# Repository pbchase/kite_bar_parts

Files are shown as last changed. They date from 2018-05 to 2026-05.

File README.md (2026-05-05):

# 3D models of components for kite control bars

This repository is a collection of 3D models for components that could be used in the construction of kite control bars. The models were created with OpenSCAD, a programming language and development environment for 3D modelling. Some of these modules are complete components that have been used in actual gear. Some are speculative designs. Other are primitives used as part of a complete component.

## How to view and manipulate these models

These OpenSCAD models can be opened, viewed, and revised using free software found at [www.openscad.org](http://www.openscad.org/). The software is available for Mac OS X, Windows, and Linux.

For the most basic use, download and install OpenSCAD. Open a model and preview it. Use the viewer controls to examine the model from all sides.

To make changes you need only basic programming skills. The editor window of OpenSCAD will show the code that generates the model. Revise the values of variables defined in the file and preview the revised model to understand how each variable affects the model. Note that all dimensions are in millimeters.

## How to print these models

To print a model, use OpenSCAD to generate a vector file in STL format. Most 3D printers can use an STL file as input.

Default 3D printer settings often use a minimal number of shells and a sparse infill that is too weak to handle the loads required  for these components. To address this, use at least 3 shells and a high infill. 80% infill is not unreasonable.

Most of these designs do not need supports. In some cases overhangs have been specifically tailored to meet the Makerbot's maximum overhang recommendation of no more than 68 degrees off vertical.

## Current models

[separation\_block_v3](separation_block_v3.scad) - This component transfers load from the main flying lines by providing a pair of parallel bore holes. Each flying line passes through a bore hole. The flying line is trapped on the lower side of the block via a larks head of relatively fat line. The pair of bore holes surround a larger, toroidal central bore hole. The curved central bore provides a low friction path for the trim line. An 80-facet-count STL files has been generated with a [8mm](printable/separation_block_v3_8mm_trimline_bore_2026-05-05.stl) trim line bore. Weaker versions of this model have been tested with a 4mm Amsteel trimline with a brummel-spliced loop on the lower end. While the trim line is only 4mm in this component, the 8mm diameter of the spliced loop must pass through it for assembly.

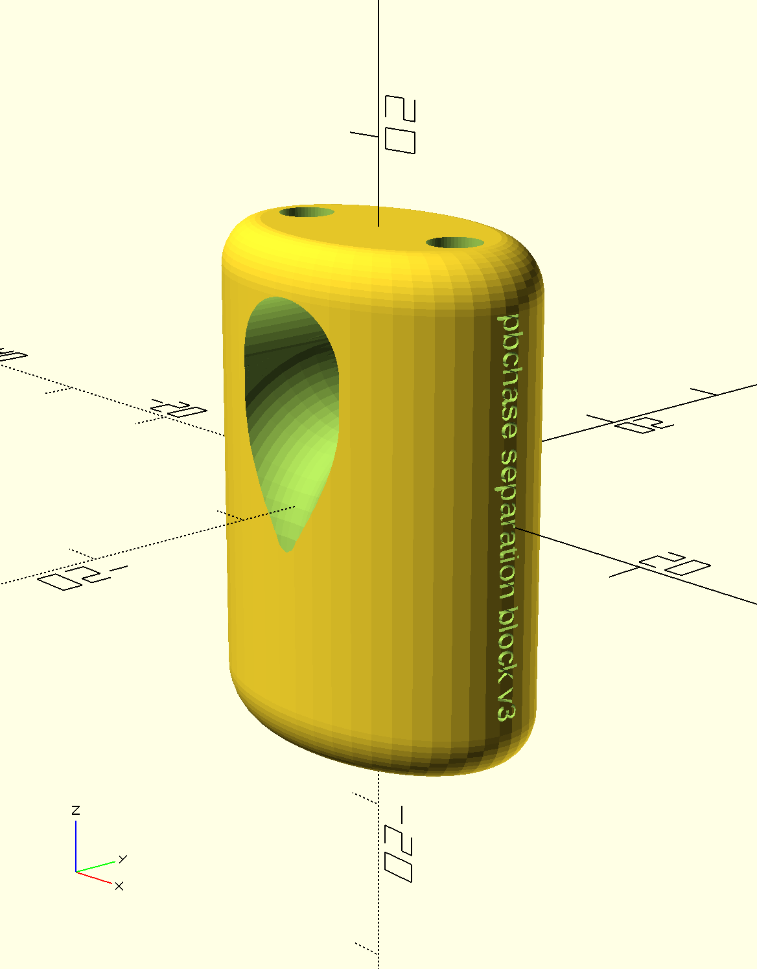
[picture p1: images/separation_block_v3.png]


[cleat_bead](cleat_bead.scad) - This component is meant to mate on to the pilot-end of [Clamcleat® CL826-11](https://www.clamcleat.com/aero-cleat-with-cl211-mk2.html). It fits tightly onto the end of the cleat with a positive rotational lock. The spherical shape conforms to the circular hole in the kite-side of the bar and allows for easy bar spinning.  The rotational lock allows for a flag-line guide path to be routed away from the jaws of the cleat to reduce the risk of cleating the flag line. STL files have been generated for [5mm](printable/cleat_bead_2026-04-28.stl) trim lines.

The small hole in the side accommodates a 18-8 Stainless Steel Cone-Point Set Screw mith 10-32 threads, 1/2 inch long. I used [item 92785A337](https://www.mcmaster.com/92785A337/) at McMaster Carr. It uses a 3/32" hex drive. Use the set screw to tap the hole by first heating it to a low heat with a torch, then screwing it in. The set screw should be screwed into the rope in the serpentine to lock the cleat bead to the cleat. This keeps the bead in place when the pilot pulls on it. 

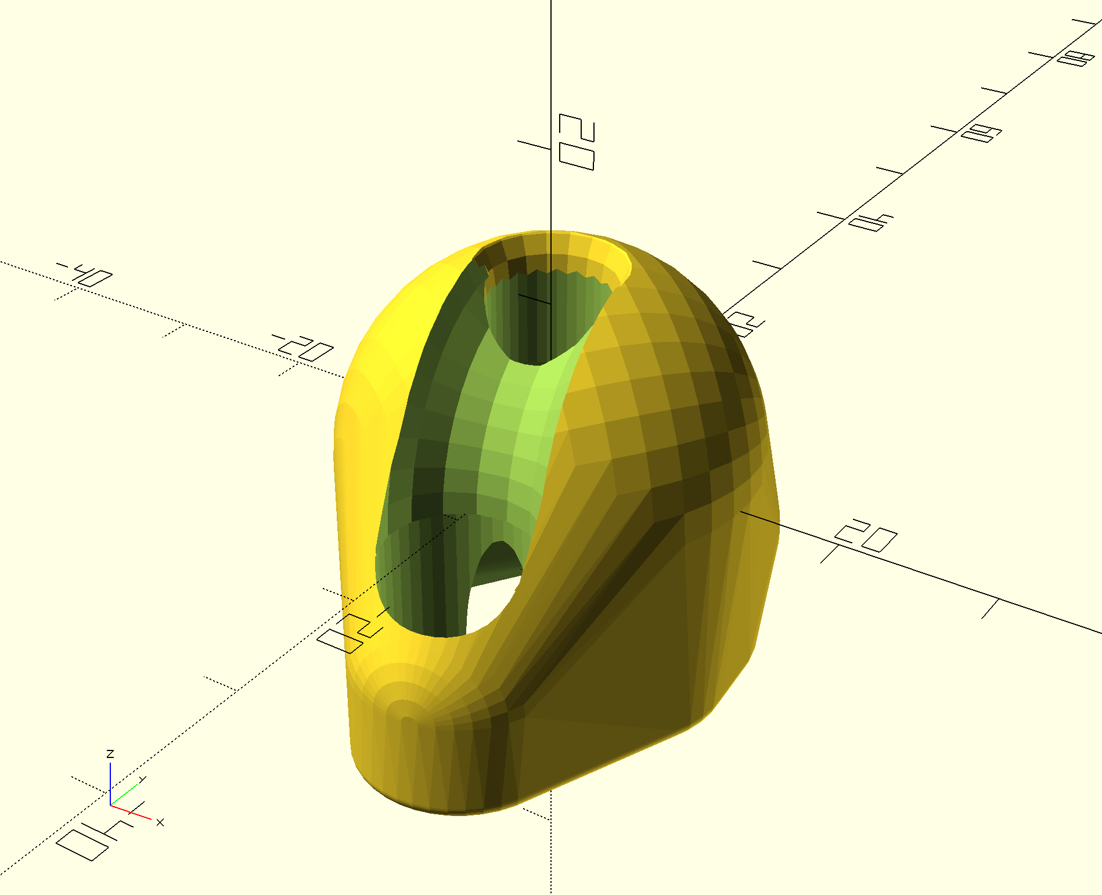
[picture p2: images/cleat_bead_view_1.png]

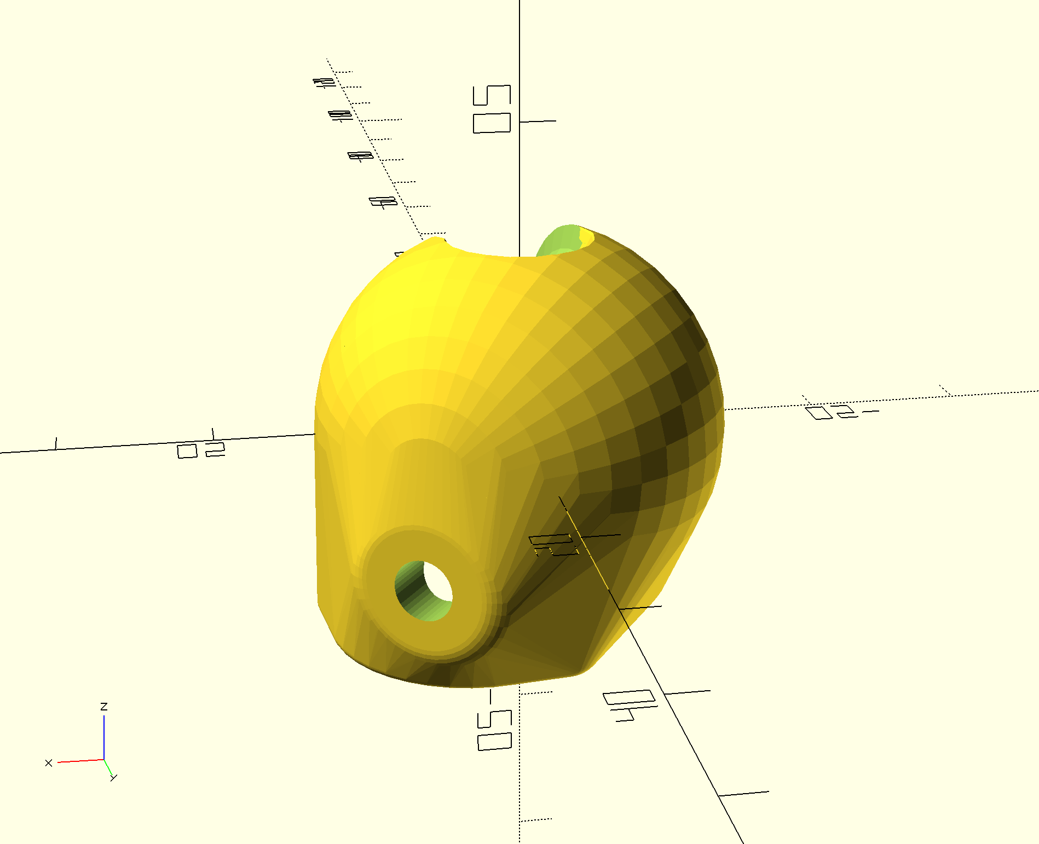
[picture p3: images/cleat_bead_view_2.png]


## Deprecated models

Several [deprecated designs](deprecated.md) and [primitives](primitives.md) used in many of these designs are also available in this repo.

## Contributing

If you would like to contribute revisions to these models or add new models feel free to fork this repo, make changes and submit a pull request. You are also welcome to open an issue and attach a file or send me files at philipbchase@gmail.com. All contributions should include a Creative Commons Public Domain license.

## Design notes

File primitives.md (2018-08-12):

### Primitives

[elliptical\_cone](elliptical_cone.scad) - a primitive the generates a vertically orients cone with a profile of 1/4 of an ellipse.

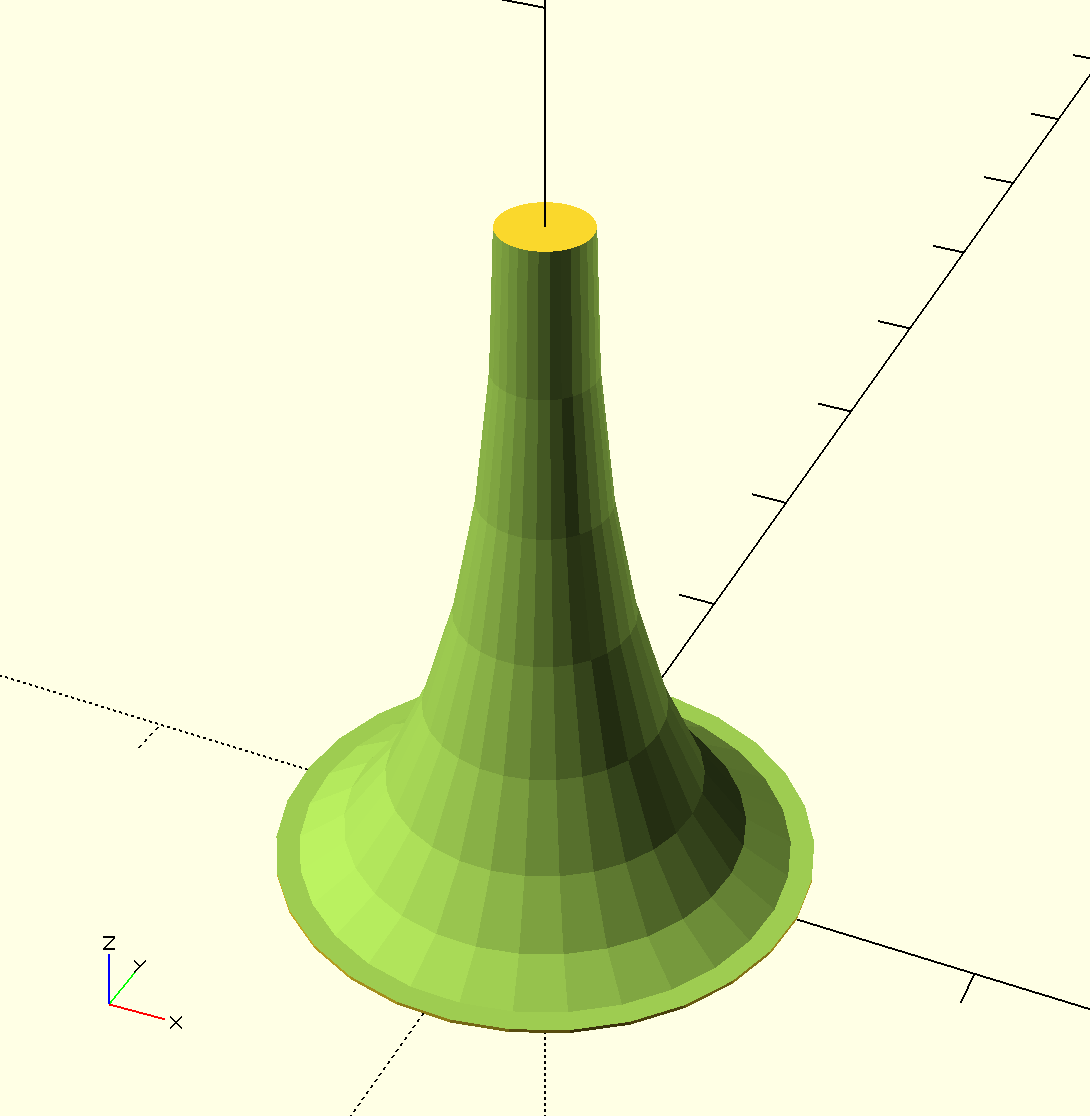
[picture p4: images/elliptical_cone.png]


[elliptical\_torus](elliptical_torus.scad) - a primitive the generates a torus with a eliptical cross section. It includes a primitive for an ellipse as well.

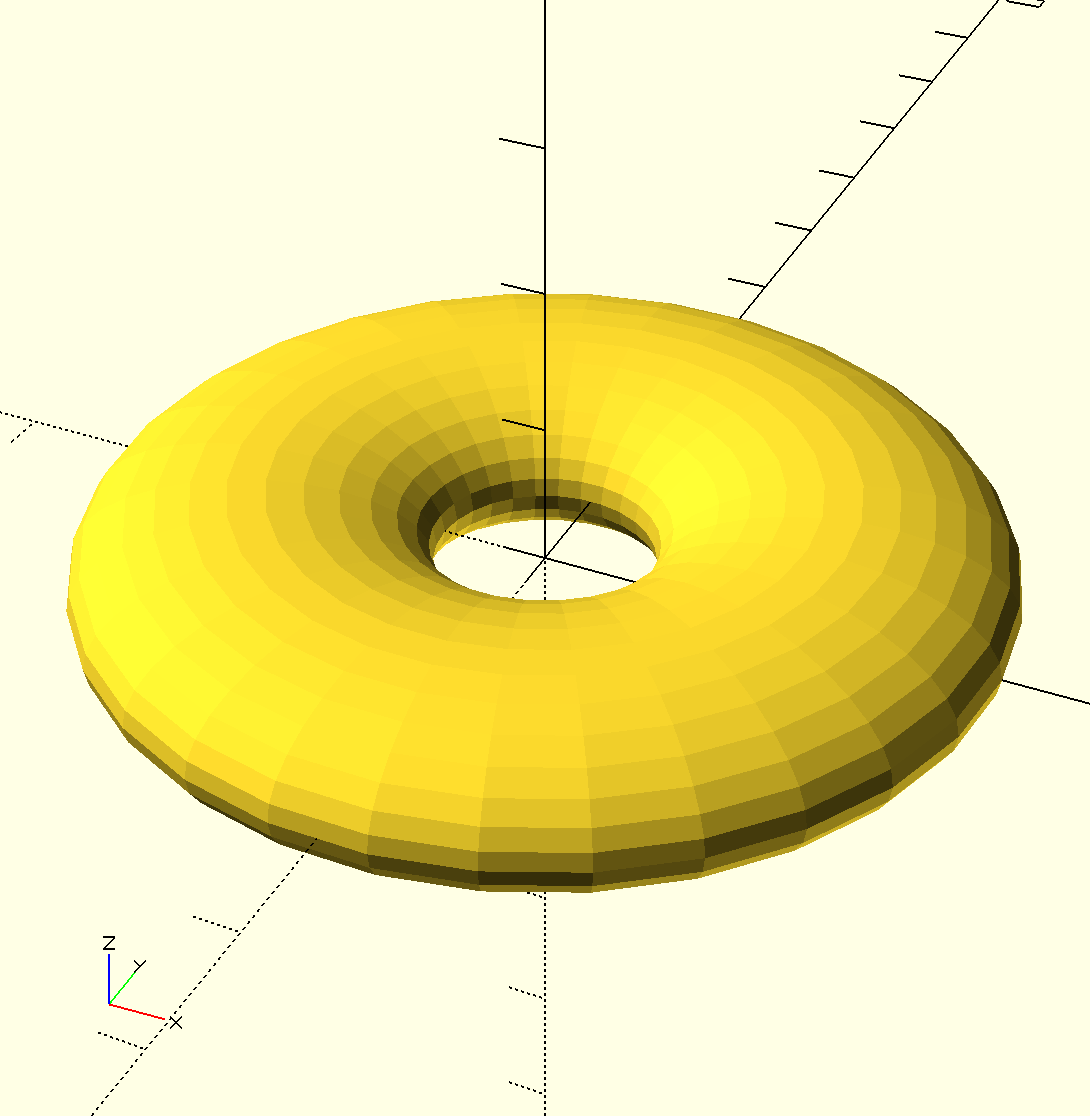
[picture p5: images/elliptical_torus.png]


[fillet\_around\_cylinder\_base](fillet_around_cylinder_base.scad) - a primitive that generates a cylinder surrounded by a 1/4 circle fillet.

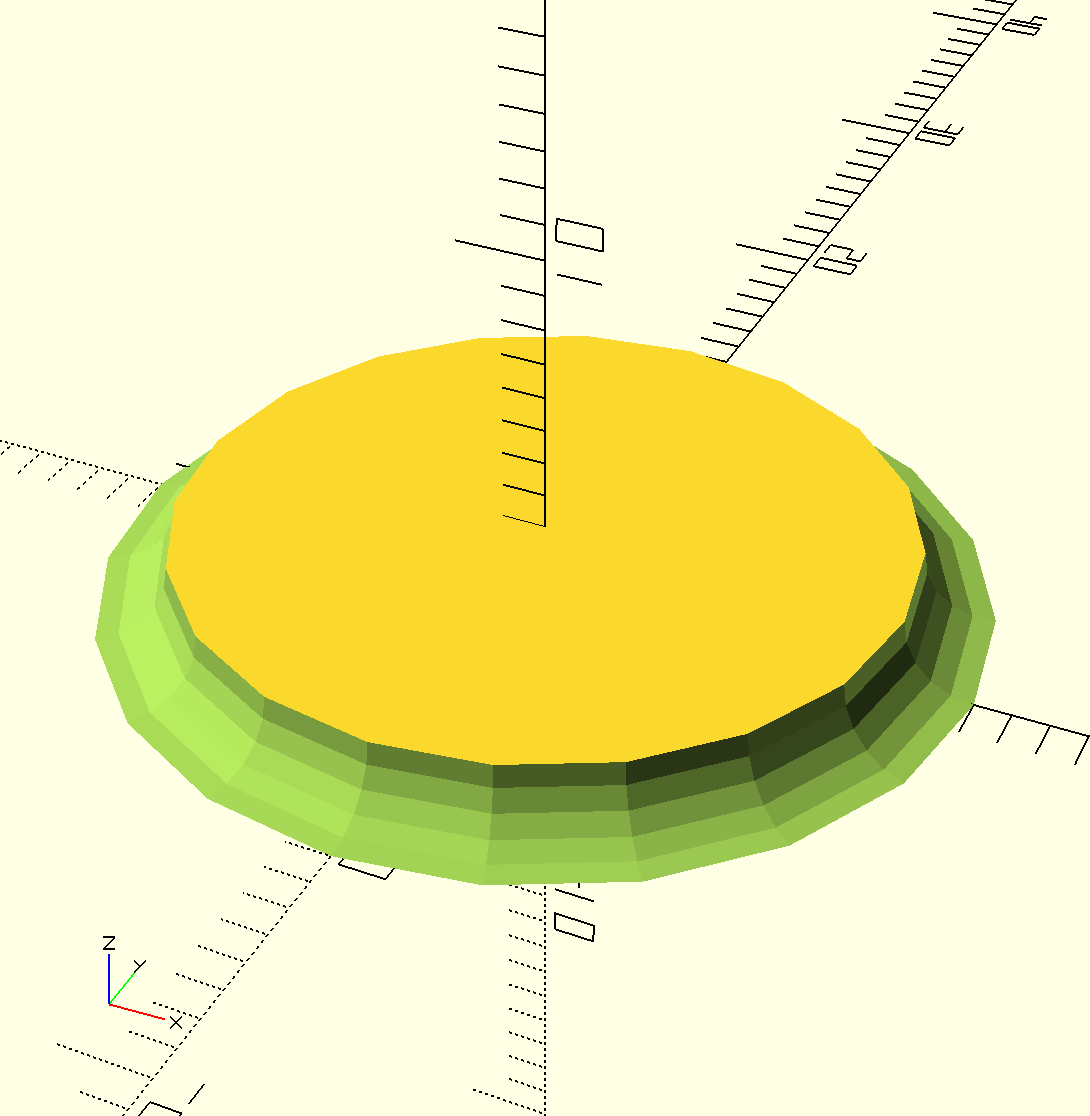
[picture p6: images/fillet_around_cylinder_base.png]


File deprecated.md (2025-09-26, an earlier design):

# Deprecated Designs

These designs have all been superceded by more functional shapes or have been otherwise retired.

## chickenloop_release

I've resisted the use of chickenloops for quite sometime, but every snap shackle I have tried presents issues in reliable use for newbies, or inadvertent release for experienced fliers. It's hard to beat the simplicity of a chickenloop with a push-away release. [chickenloop_release](chickenloop_release.scad), is the model for that release. The release doubles as a below-the-bar handle for the kite. As an Arc flier this is valuable feature for handling the kite while it's parked at zenith. The release is designed to accommodate a doubled trimline of 4mm Amsteel Blue through the center bore. A 0.102" stainless steel pin crosses and divides the center bore to provide a retainer for the trimline. The prototypes for this model use a 40mm stainless steel cotter pin to retain the free end of the chickenloop. The side bores retain a segment of 1/8" bungie that pushes the chickenloop and cotter pin together. A 90-facet-count [STL file](printable/chickenloop_release_d1928a2.stl) is available.

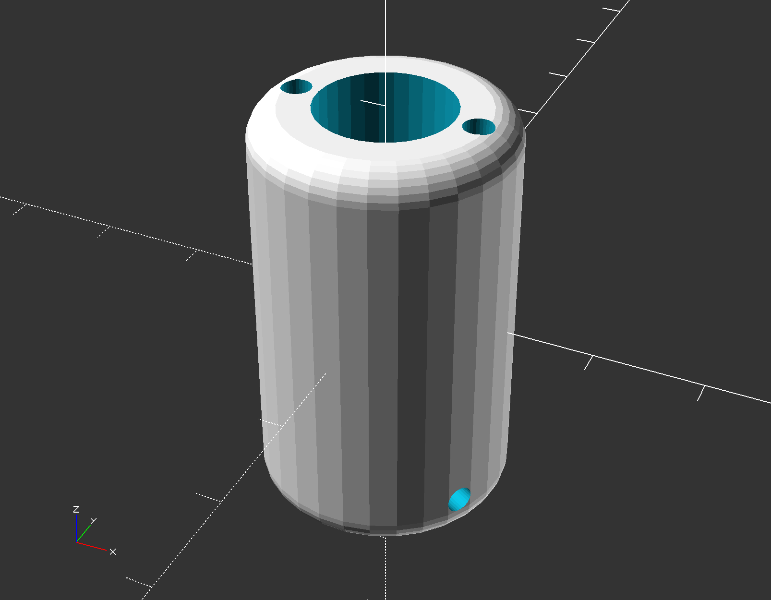
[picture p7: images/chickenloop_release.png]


[stopper\_ball](stopper_ball.scad) - The ball used in a moveable stopper on a kite bar trim line. STL files have been generated for
[4mm\_amsteel\_blue\_trimline](printable/stopper_ball_4mm_amsteel.stl) and
[5mm\_amsteel\_blue\_trimline](printable/stopper_ball_modern_5mm_amsteel.stl). The previous iteration of this ball was field tested and worked very well. This iteration removes a twist in the bungie path. To print it reliably, use a support structure that surrounds the base.

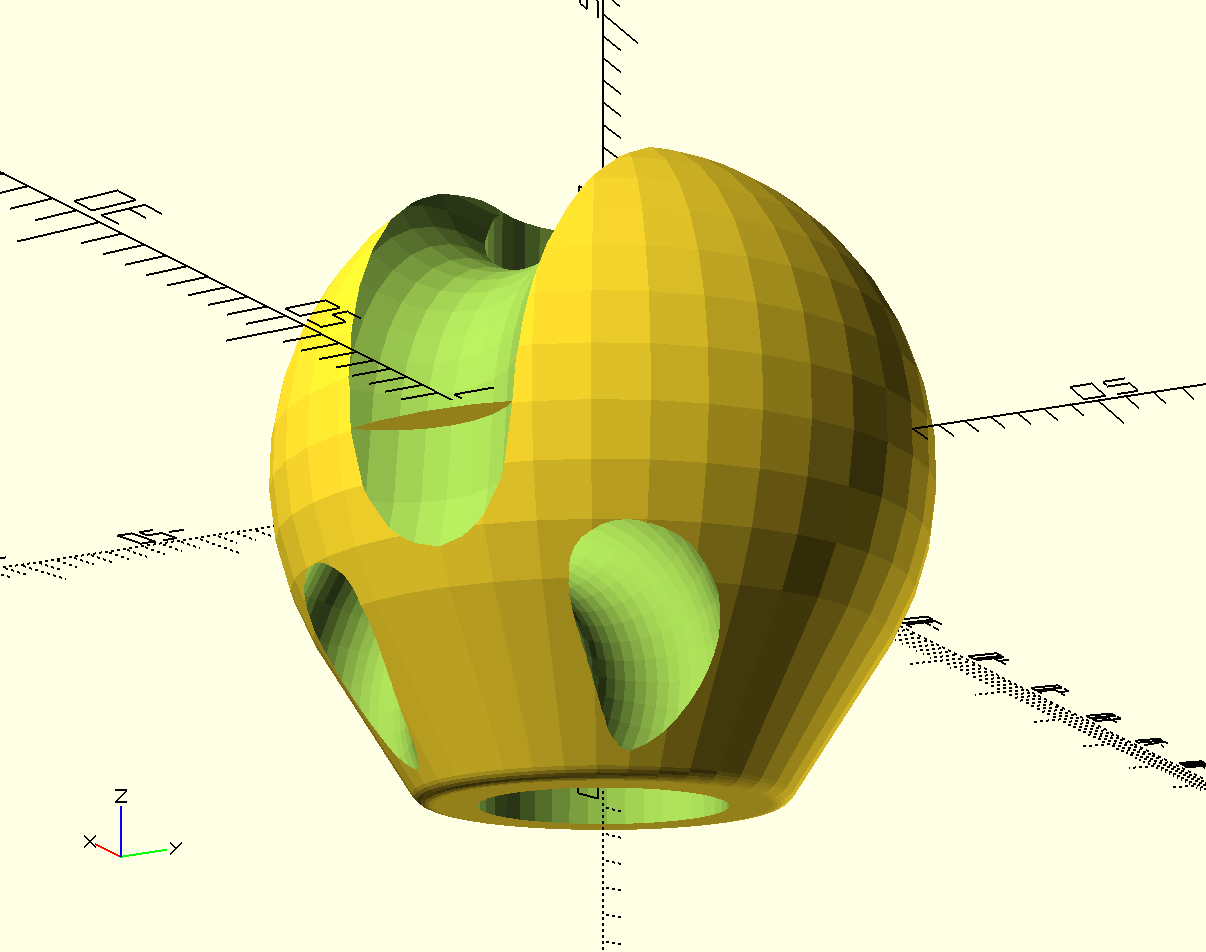
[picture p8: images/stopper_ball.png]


[stopper\_block\_v4](stopper_block_v4.scad) - This block is used in tandem with the stopper ball to form a moveable stopper. A slightly earlier version of this design has been field tested. This version should be easier to print than the previous version. STL files have been generated for
[4mm\_amsteel\_blue\_trimline](printable/stopper_block_v4_4mm_amsteel.stl) and
[5mm\_amsteel\_blue\_trimline](printable/stopper_block_v4_modern_5mm_amsteel.stl).

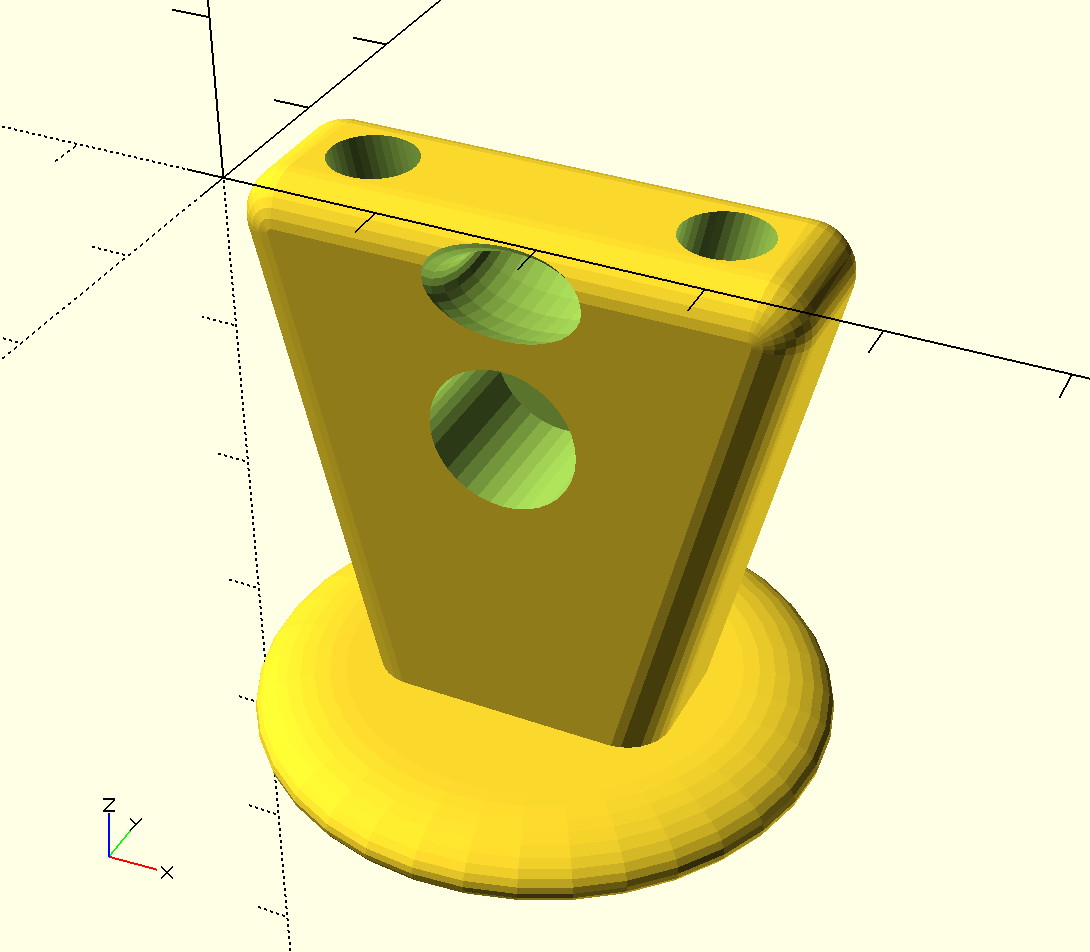
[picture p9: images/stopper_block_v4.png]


[separation\_block_v1](separation_block_v1.scad) - This component transfers load from the main flying lines by providing a pair of parallel bore holes. Each flying line passes through a bore hole. The flying line is trapped on the lower side of the block via a larks head of relatively fat line. The pair of bore holes surround a larger, central bore hole. The central bore hole allows a heavier line to be secured to the separation block. The upper end is secured via an overhand knot. The lower end of the central line entraps a low friction ring that acts as a pulley for the trim line. An [STL File](printable/separation_block_v1_9a972b6.stl) is available.

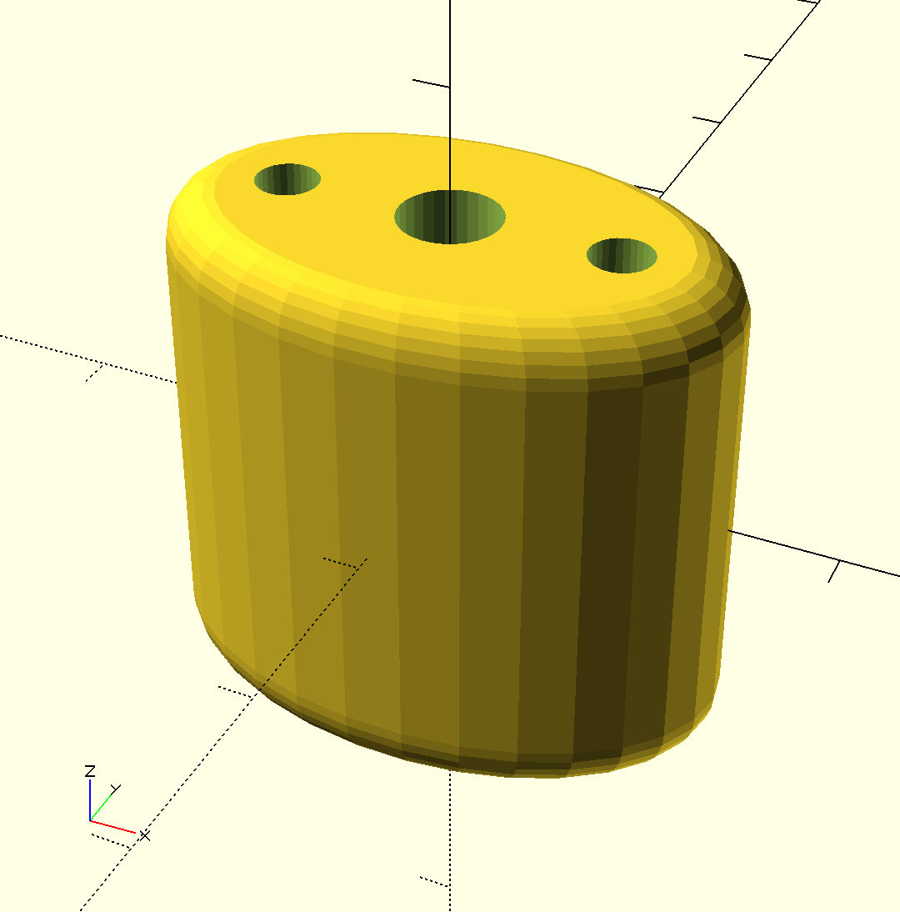
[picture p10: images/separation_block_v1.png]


**Three part wichard snaphook** -  This design is uses six components to form a fid and a handle to actuate a wichard snaphook. The components are
[wichard\_snaphook\_handle\_concave\_link](wichard_snaphook_handle_concave_link.scad),
[wichard\_snaphook\_cone\_fid](wichard_snaphook_cone_fid.scad) and
[wichard\_snaphook\_handle\_for\_cone\_fid](wichard_snaphook_handle_for_cone_fid.scad).  [STL files](printable/) are available for each.  A pair of each component is printed to out fit a single snaphook. This design accidentally released once in a 3 hour session. That's still too high.

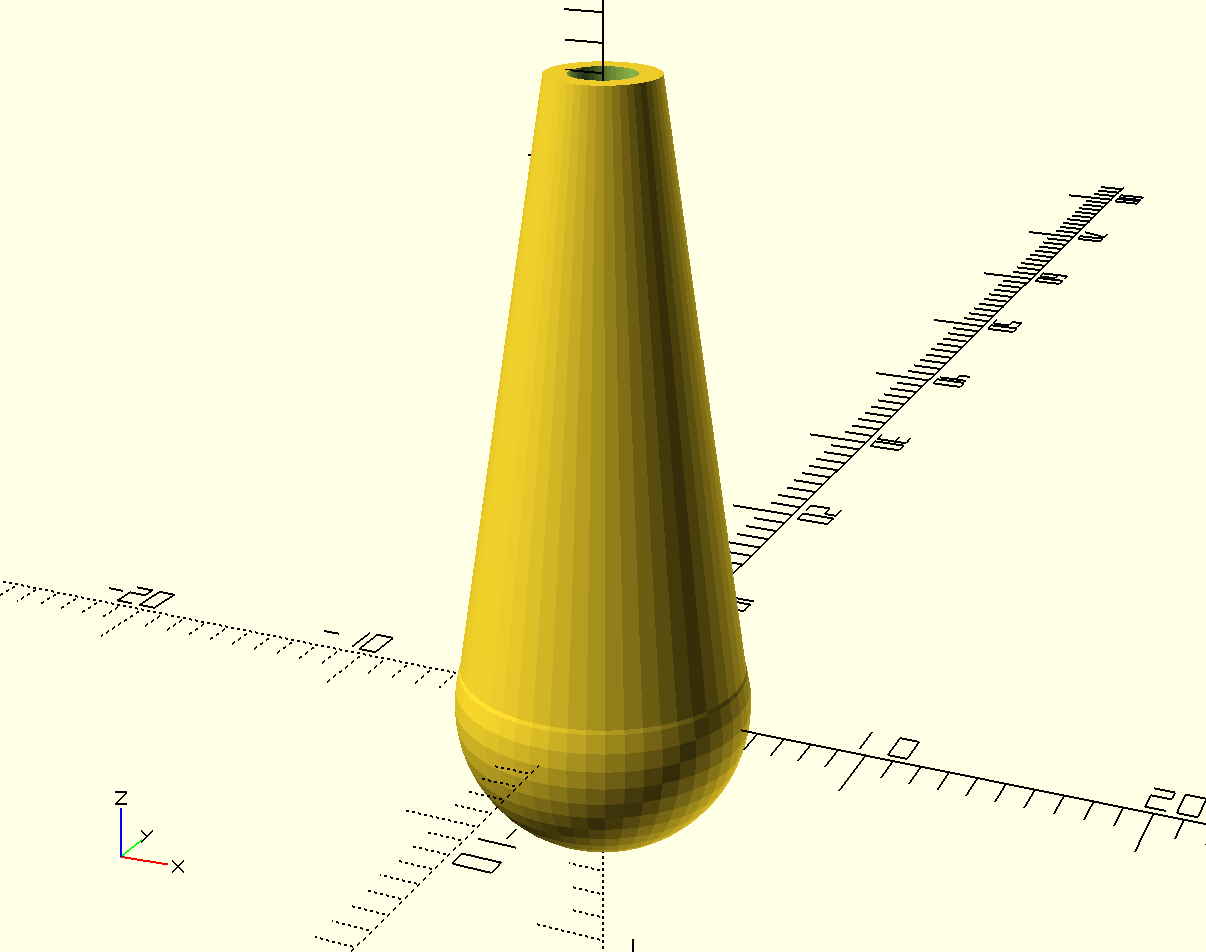
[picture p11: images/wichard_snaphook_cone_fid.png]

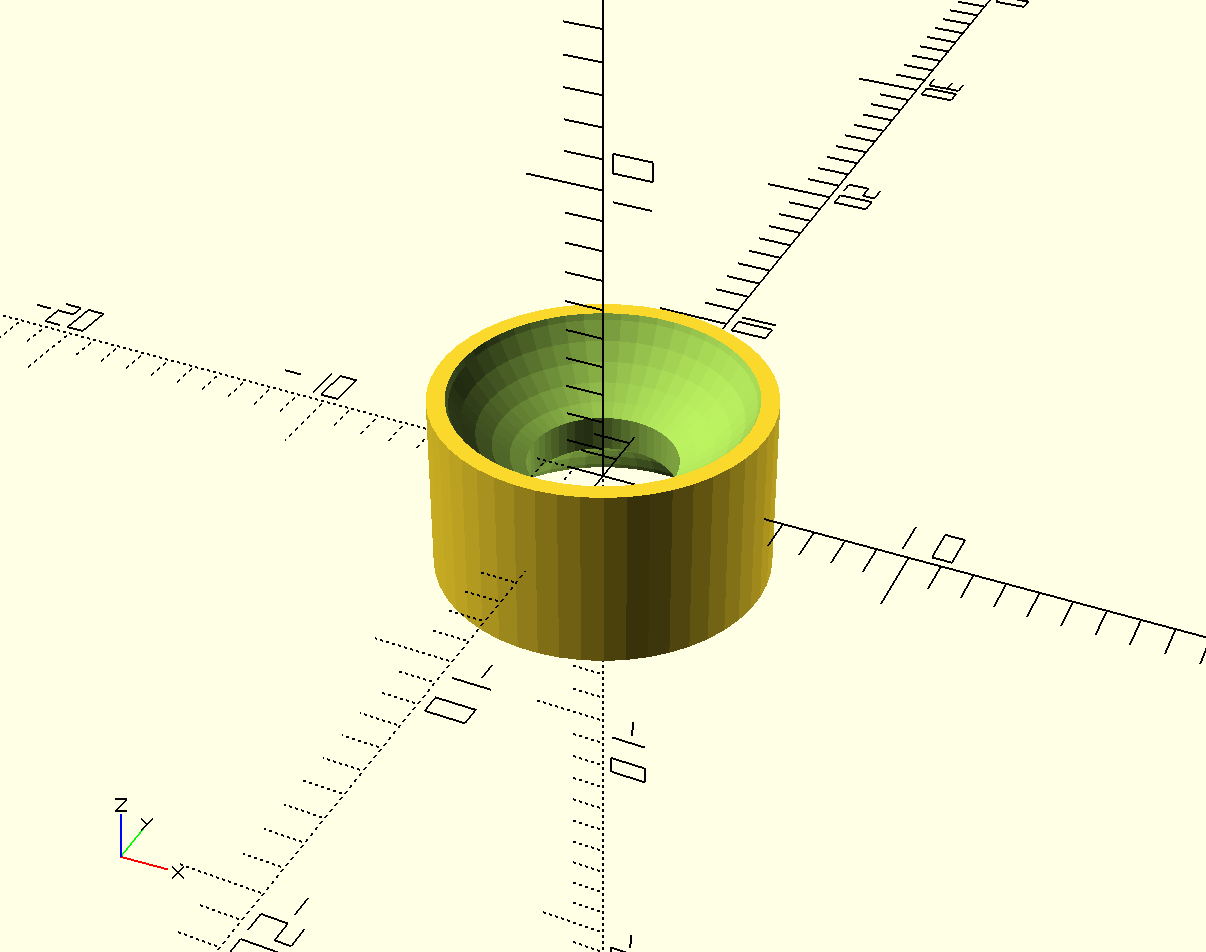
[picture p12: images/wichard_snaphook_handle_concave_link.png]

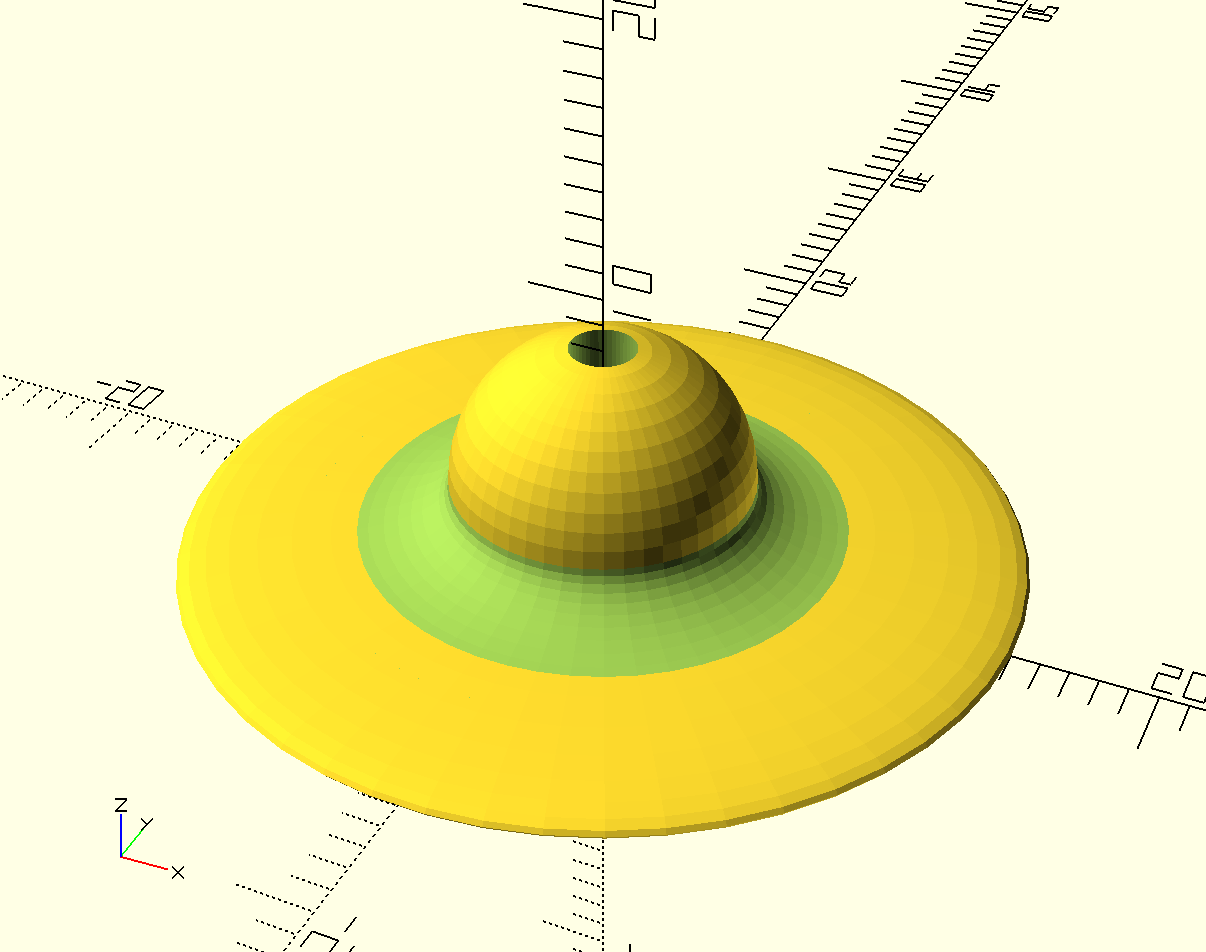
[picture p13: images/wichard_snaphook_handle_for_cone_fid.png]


[wichard\_snaphook\_handle\_golf\_tee\_style](wichard_snaphook_handle_golf_tee_style.scad) - a cone-and-flange handle to open the gate of a Wichard Snap shackle. An [STL file](printable/wichard_snaphook_handle_golf_tee_style_8677c59.stl) is available. While this model reliably opens the gate and does so with little force it has opened unexpectedly in field testing. This happened three times in about 5 hours of testing. The problem occurs when the harness and the handles are forced down onto the pilot's thigh. Apprently, the base of the handle stands on the thigh as the snap hook is forced down against the thigh. This pulls the cord in the gate, pulls the opposite handle into the gate and triggers the release. See  _Untested Models_ below for the next iteration of the design.

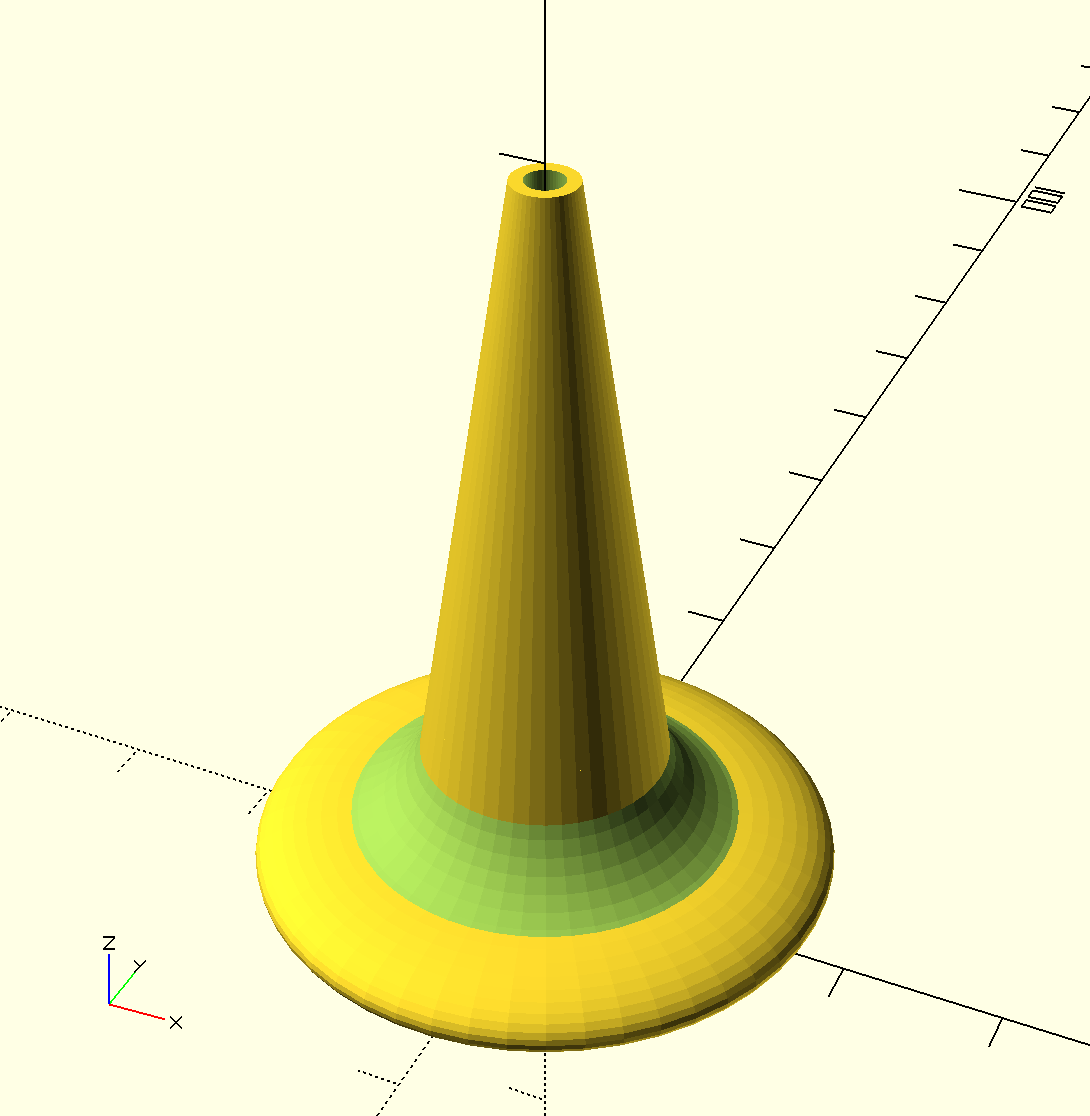
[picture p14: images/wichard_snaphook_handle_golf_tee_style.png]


[wichard\_snaphook\_handle](wichard_snaphook_handle.scad) - a cone-and-ball handle to open the gate of a Wichard Snap shackle. The wall thickness is thin at the base of the cone and the transition is harsh.

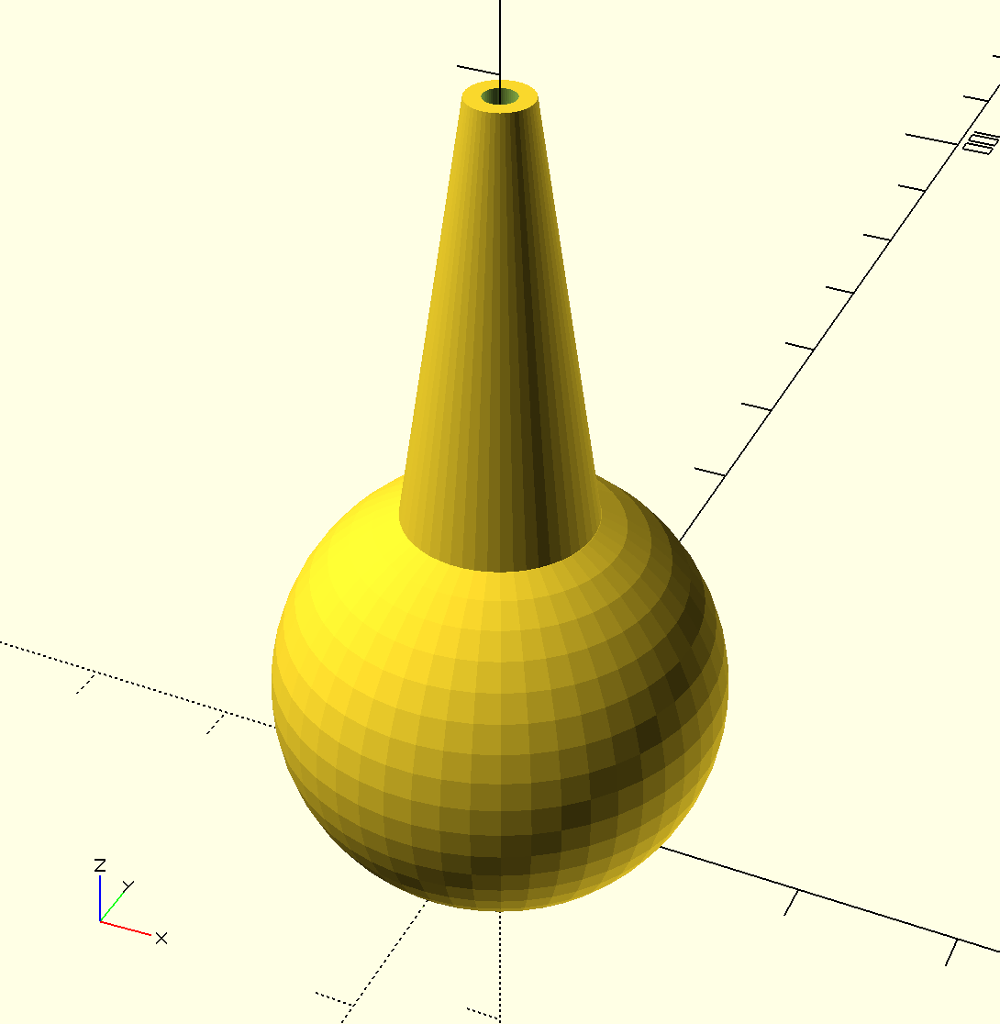
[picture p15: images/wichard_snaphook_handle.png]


[stopper\_block\_v3](stopper_block_v3.scad) - This block is used in tandem with the stopper ball to form a moveable stopper. This 3D model has never been tested in the field. It is 4mm narrow than stopper\_block\_v2 and uses octagonal horizontal bores to reduce overhang issues when printing. An [STL file](printable/stopper_block_v3_9c3c682.stl) is available.

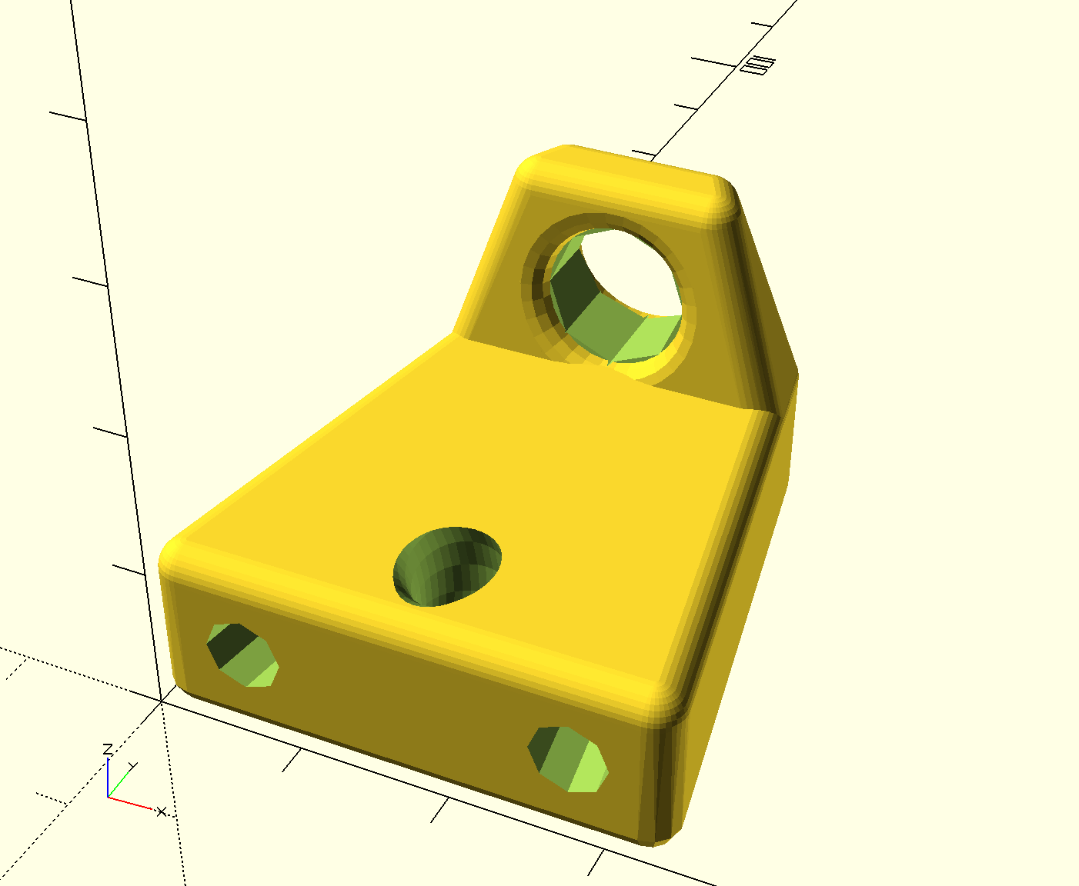
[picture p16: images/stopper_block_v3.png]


[stopper\_block\_v2](stopper_block_v2.scad) - This block is used in tandem with the stopper ball to form a moveable stopper. This 3D model has never been tested. That said, it is based on a hand-made design, cut from Delrin, that has been tested extensively. This model is closer to the hand-made design than the original [stopper\_block](stopper_block.scad) model.

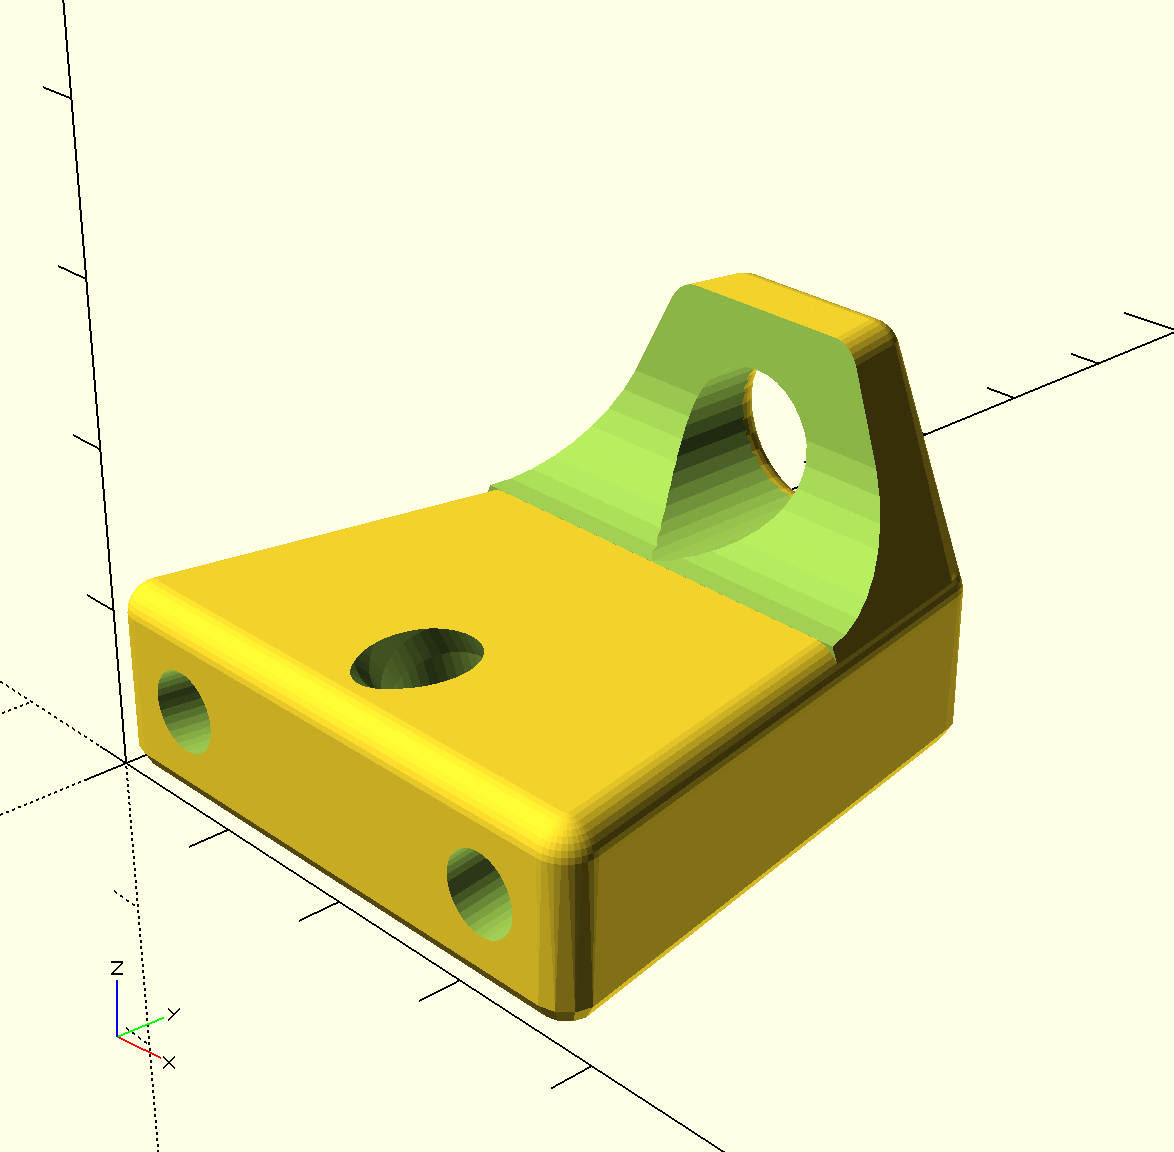
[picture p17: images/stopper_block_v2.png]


[stopper\_block](stopper_block.scad) - This block is used in tandem with the stopper ball to form a moveable stopper.  This 3D model has never been tested. That said, it is based on a hand-made design, cut from Delrin, that has been tested extensively.  The edges of this model are far harsher than what is possible when machining such a block from Delrin. The harsh edges might make it unsuitable for regular use.

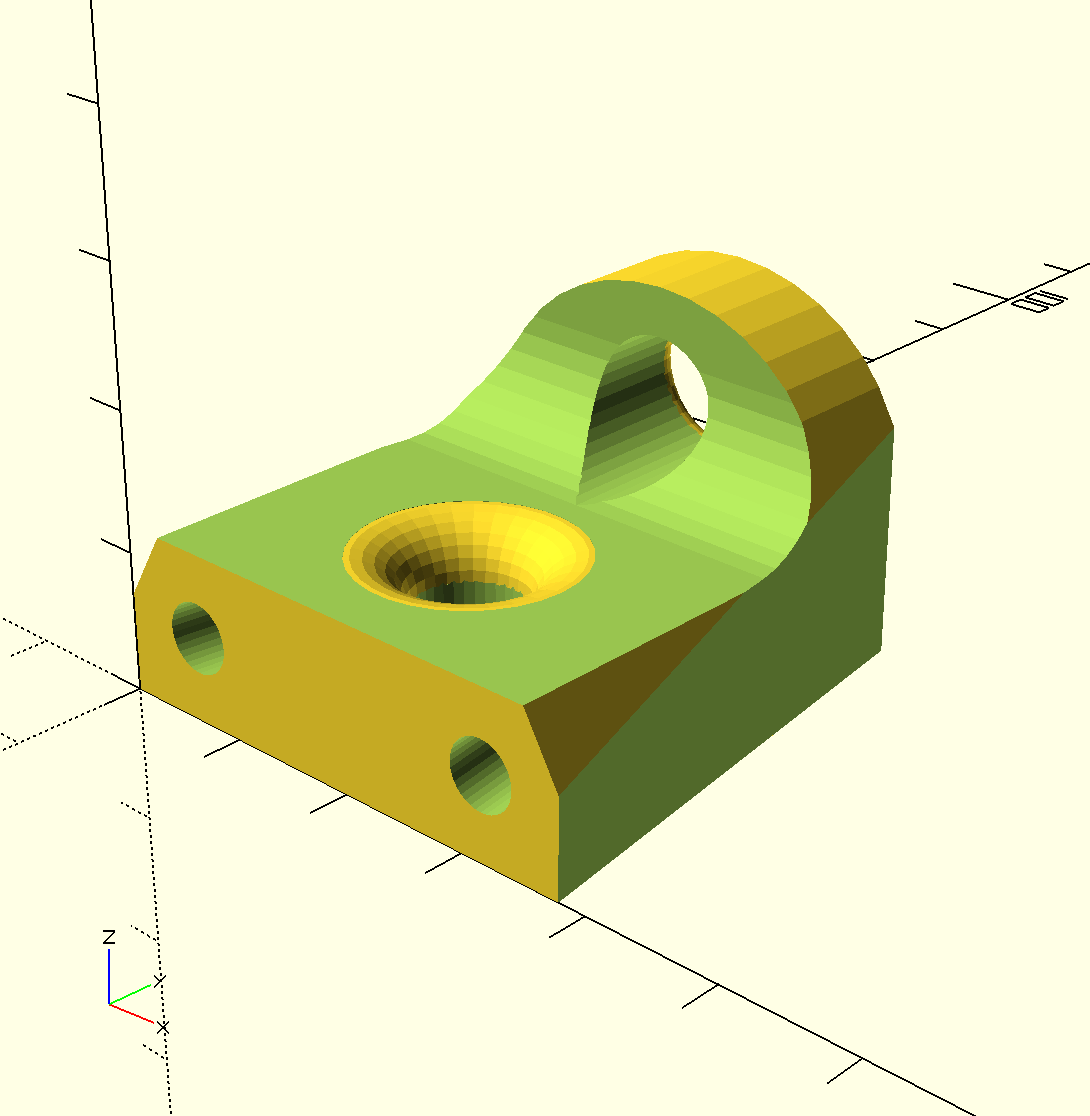
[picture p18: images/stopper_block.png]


[wichard\_snaphook\_release\_cone](wichard_snaphook_release_cone.scad) - a cone to open the gate of a Wichard Snap shackle.  This component has never been tested.

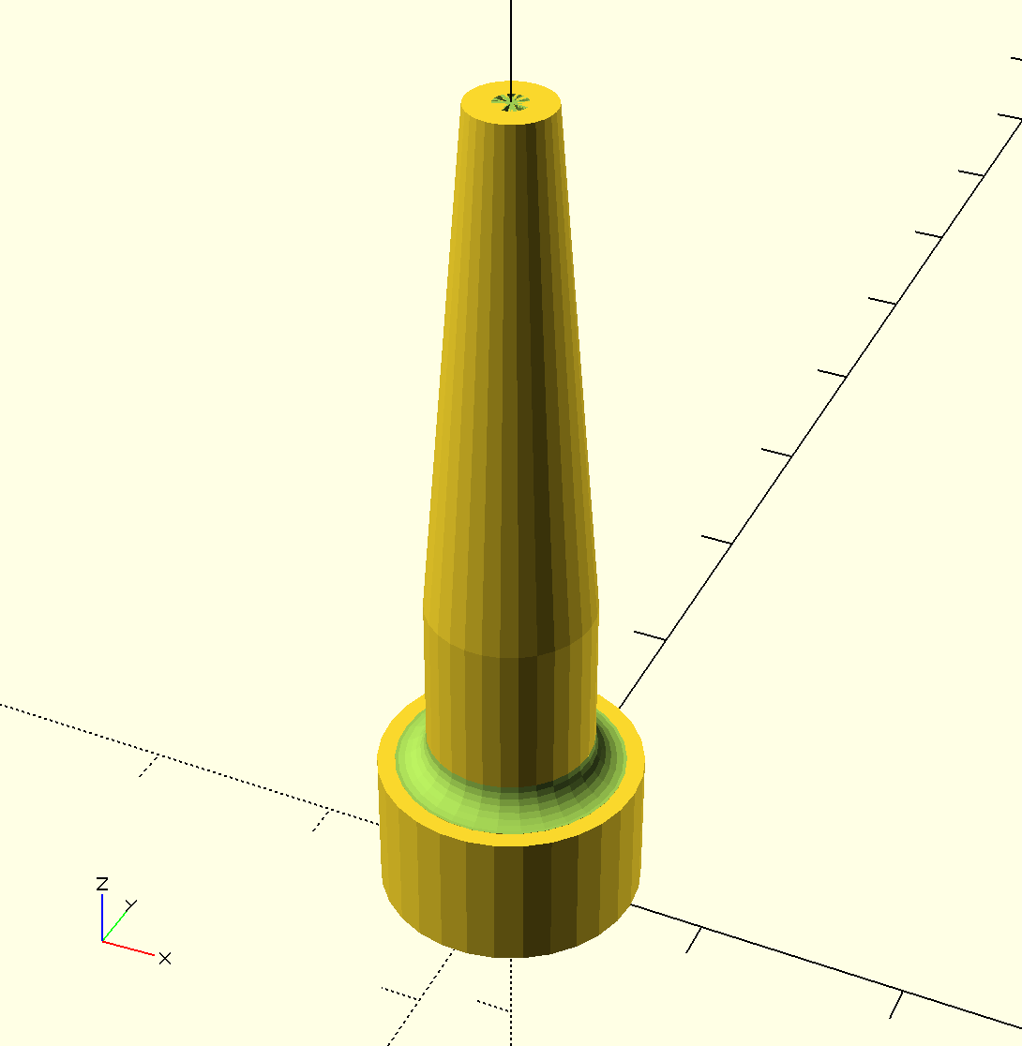
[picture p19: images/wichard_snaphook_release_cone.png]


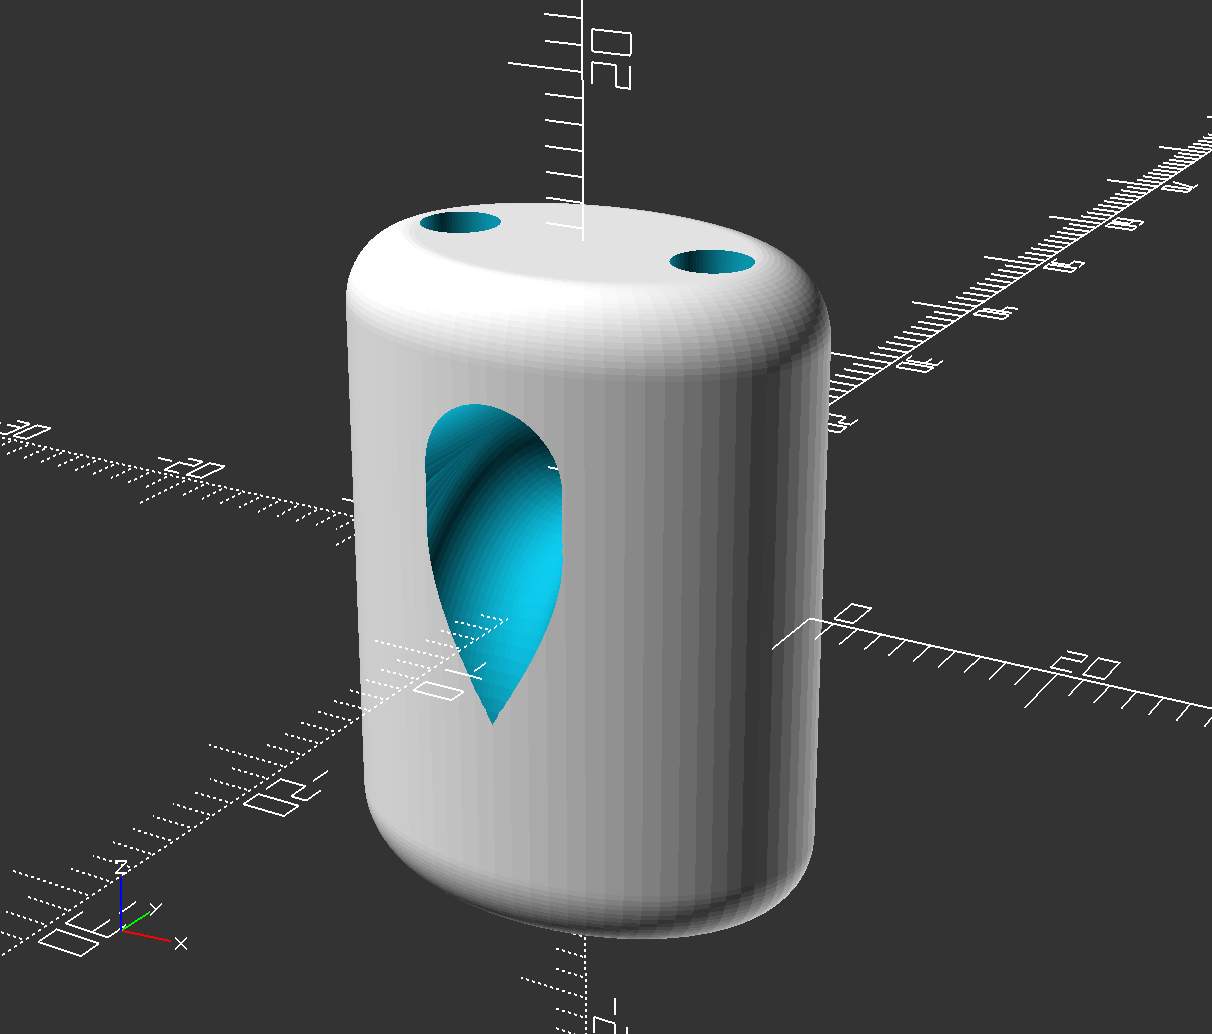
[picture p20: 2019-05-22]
images/separation_block_v2.png

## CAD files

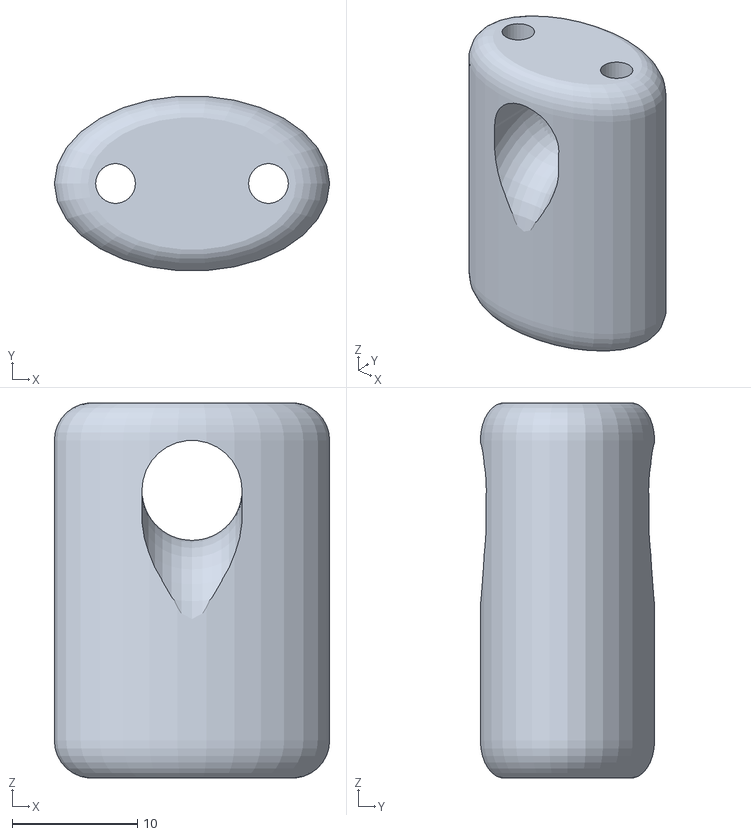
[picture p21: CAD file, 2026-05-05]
printable/separation_block_v3_8mm_trimline_bore_2026-05-05.stl
22.0 x 13.9 x 30.0

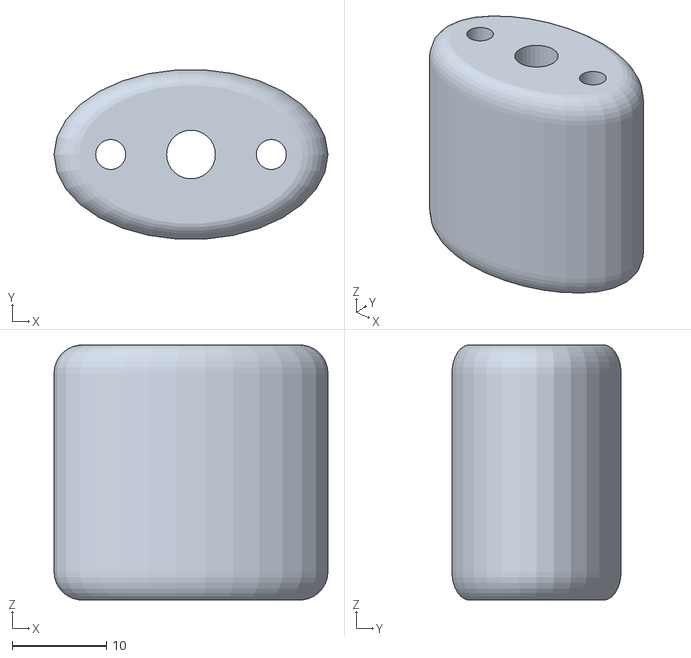
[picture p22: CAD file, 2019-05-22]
separation_block_v1.stl
29.0 x 17.9 x 27.0

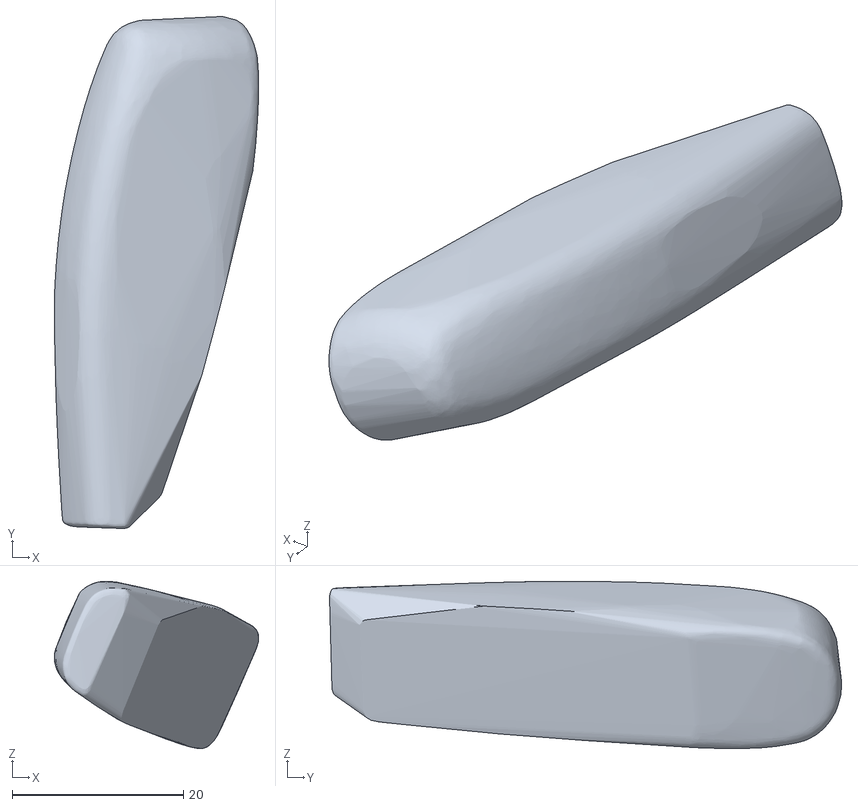
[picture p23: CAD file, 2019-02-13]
CL826-11AN_20190212_truncated_and_hulled.stl
23.9 x 59.7 x 19.5

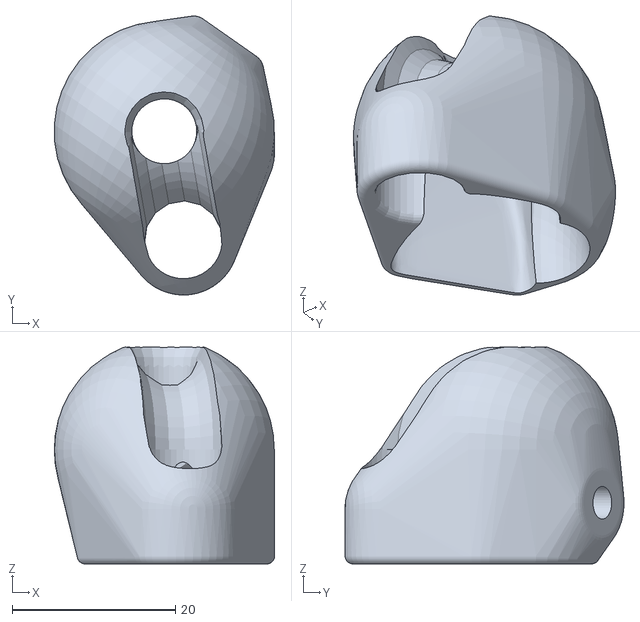
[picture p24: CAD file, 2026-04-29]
printable/cleat_bead_2026-04-28.stl
27.0 x 34.2 x 26.6

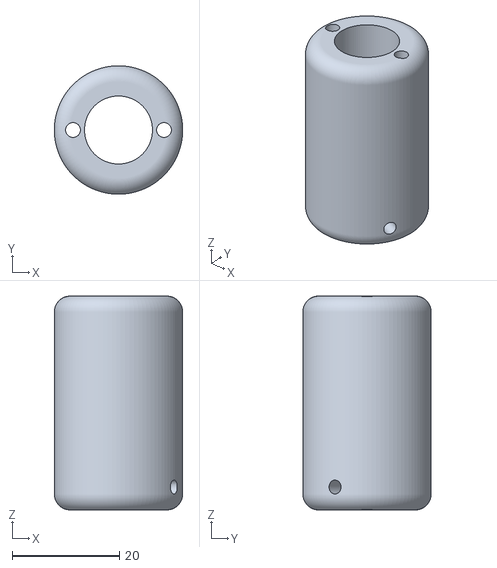
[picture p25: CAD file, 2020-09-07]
printable/chickenloop_release_d1928a2.stl
24.0 x 24.0 x 40.0

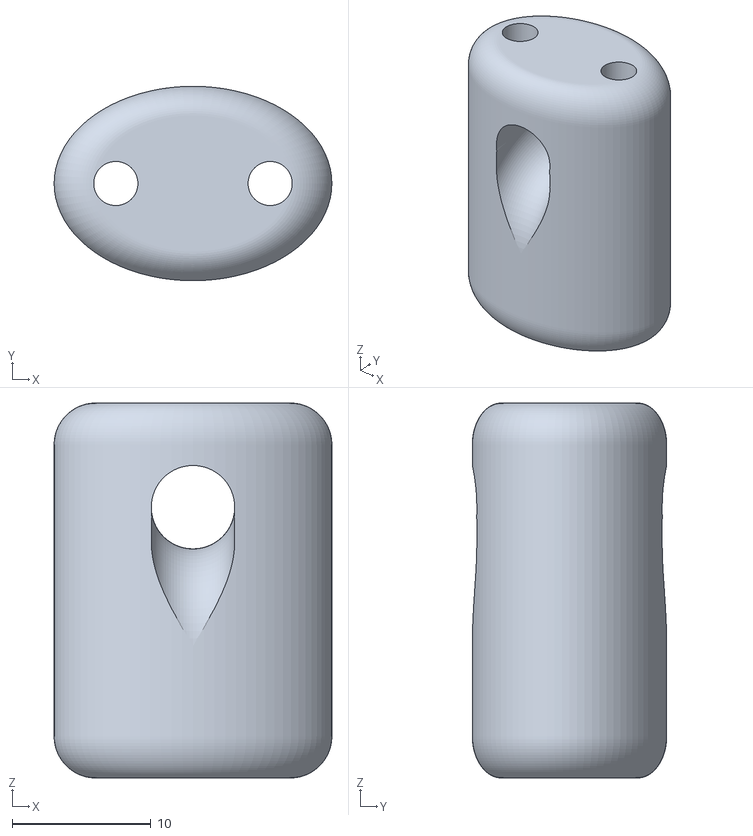
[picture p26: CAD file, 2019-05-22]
printable/separation_block_v2_6mm_trimline_bore_7e61bdd.stl
20.0 x 14.0 x 27.0

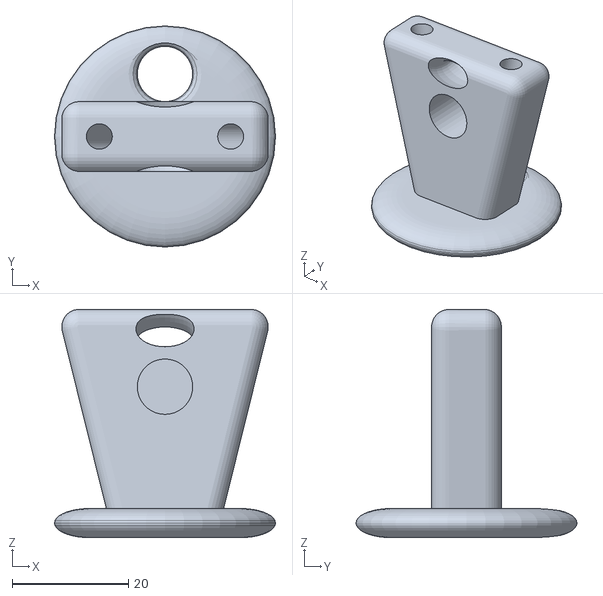
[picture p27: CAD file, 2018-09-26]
printable/stopper_block_v4_4mm_amsteel.stl
38.0 x 38.0 x 39.2

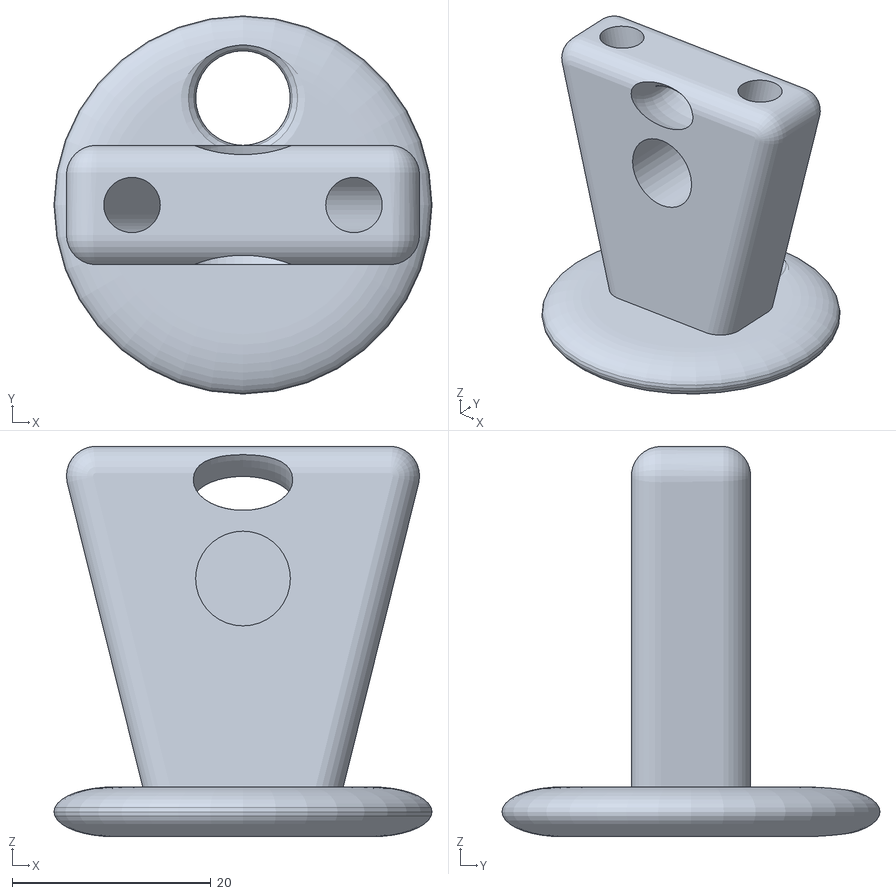
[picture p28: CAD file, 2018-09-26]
printable/stopper_block_v4_modern_5mm_amsteel.stl
38.0 x 38.0 x 39.2

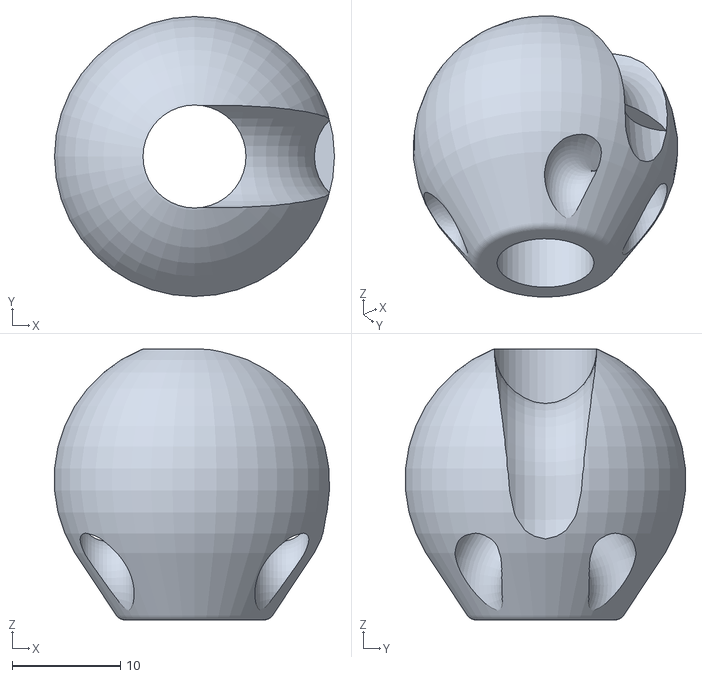
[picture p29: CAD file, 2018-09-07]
printable/stopper_ball_modern_5mm_amsteel.stl
25.9 x 25.9 x 25.1

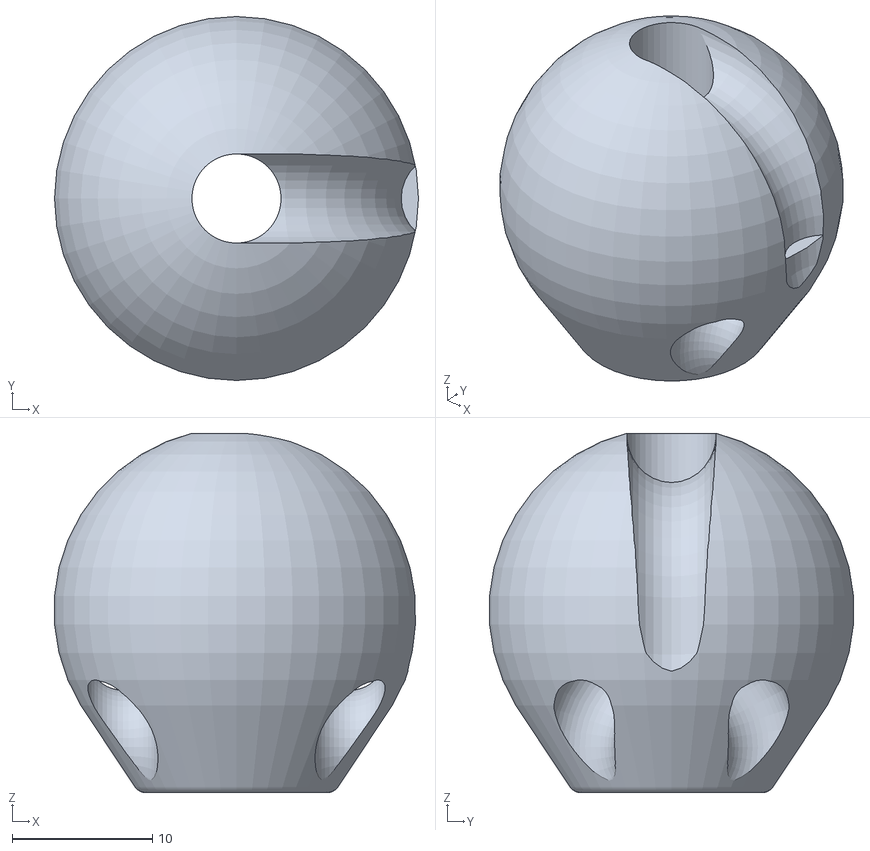
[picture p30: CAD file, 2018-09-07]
printable/stopper_ball_4mm_amsteel.stl
25.9 x 25.9 x 25.6

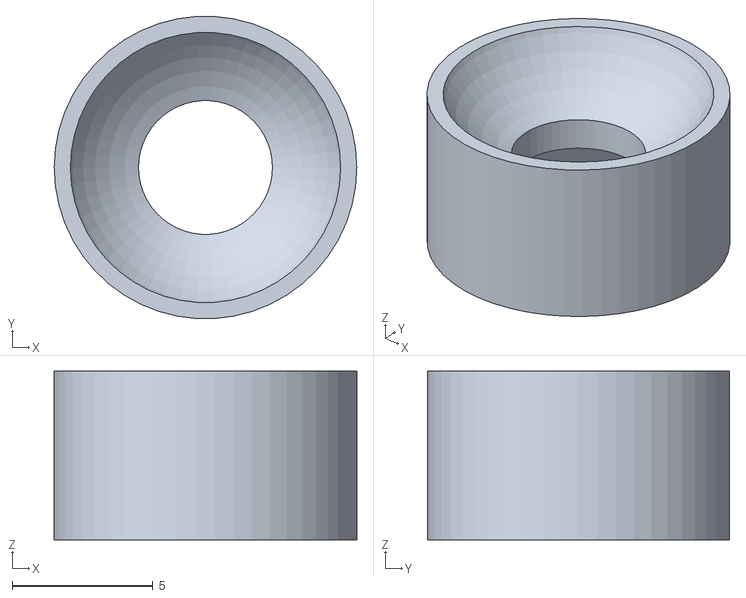
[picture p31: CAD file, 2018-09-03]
printable/wichard_snaphook_handle_concave_link_642d71c.stl
10.8 x 10.7 x 6.00

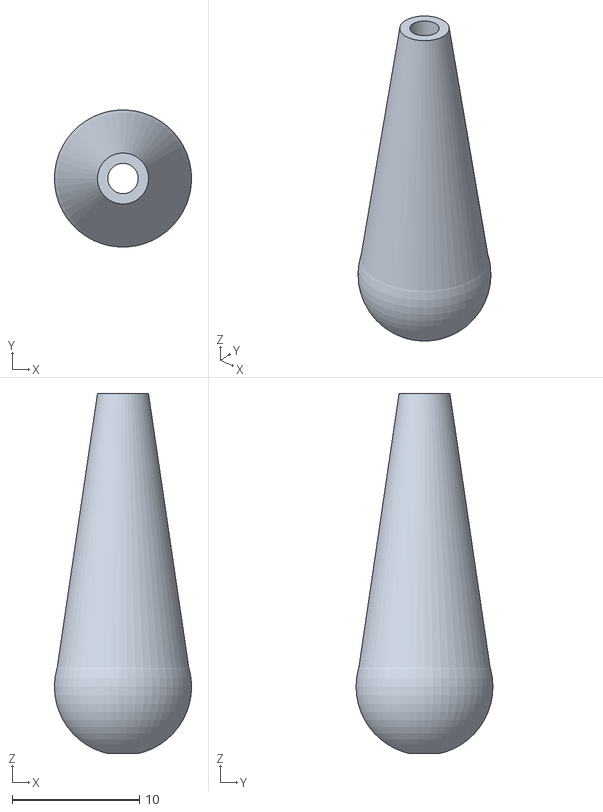
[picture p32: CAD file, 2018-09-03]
printable/wichard_snaphook_cone_fid_642d71c.stl
10.8 x 10.7 x 28.2

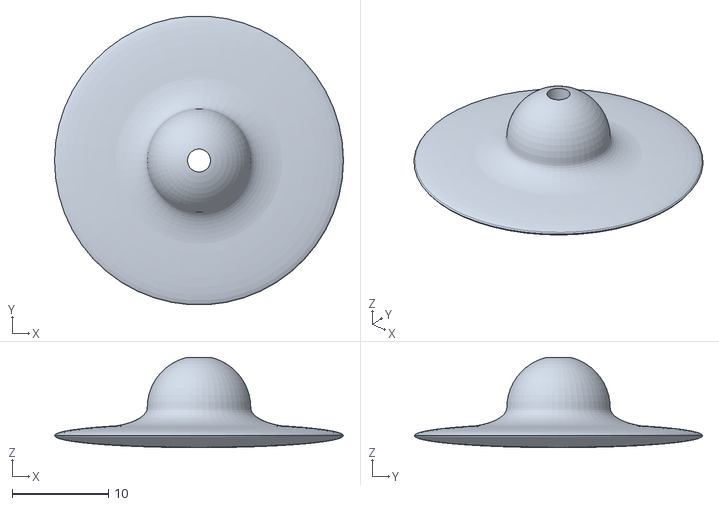
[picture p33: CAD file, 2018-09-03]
printable/wichard_snaphook_handle_for_cone_fid_642d71c.stl
30.0 x 29.9 x 9.37

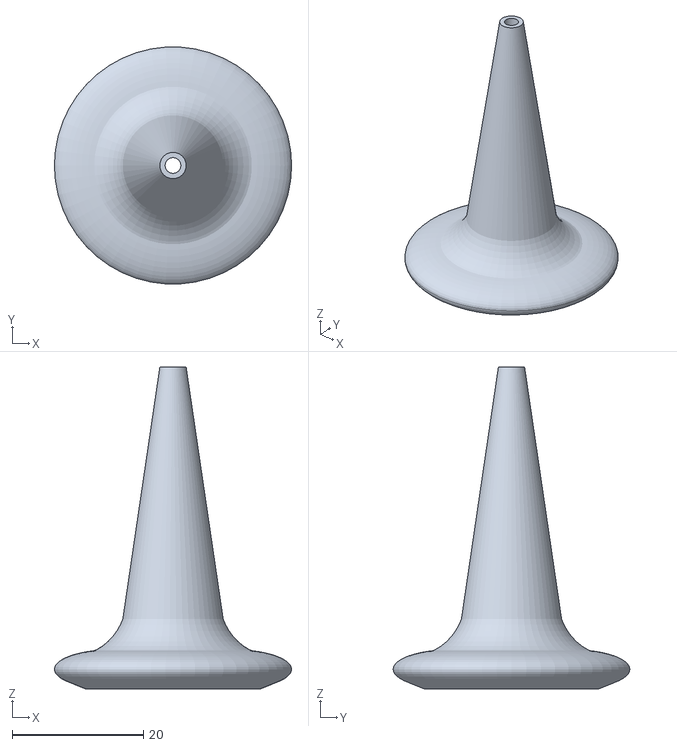
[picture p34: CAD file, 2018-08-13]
printable/wichard_snaphook_handle_golf_tee_style_8677c59.stl
36.1 x 36.0 x 49.0

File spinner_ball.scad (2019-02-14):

// 3D model for a spinner ball for a kite-bar control system
// See http://philipbchase.com/
// Make one per kite bar
// Author: Philip B Chase, <philipbchase@gmail.com>
/* This design is meant to mate on to the pilot-end of Clamcleat® CL826-11. It fits tightly onto the end with a positive rotational lock. The spherical shape conforms t the circular hole in the kite-side of the bar and allows for easy bar spinning.  The rotational lock allows for a flag-line guide path to be reliably located opposite the cleat to reduce the risk of cleating the flag line. 
*/
/* License: To the extent possible under law, Philip B Chase has waived all copyright and related or neighboring rights to 3D model for a spinner ball for a kite-bar control system. This work is published from: United States.  See: http://creativecommons.org/publicdomain/zero/1.0/

    Scans of the Clamcleat CL826-11AN are copyright Clamcleats Limited, UK
*/

use <elliptical_torus.scad>;
$fn=30;

// Define major dimension of ball
ball_r = 26/2;

// Define dimension of large center bore for the pair of trim lines
// The line diameters here have all been tested using a wrap of insignia cloth
// around the line end to provide a threading end. This slightly increases the
// line diameter, but is very helpful for routing the line through the
// stopper and ball. In each case, the width of the cloth wrapped around the
// line as 4 times the nominal line diameter. Aka, slightly more than Pi and
// slightly more than one wrap.
bore_diameter_for_4mm_amsteel = 1/4 * 25.4;
bore_diameter_for_old_5mm_amsteel = 5/16 * 25.4;
bore_diameter_for_modern_5mm_amsteel = 3/8 * 25.4;
bore_diameter_for_5mm_ultrex = 3/8 * 25.4;
trim_line_diameter=bore_diameter_for_modern_5mm_amsteel;

trimline_bore_r=trim_line_diameter/2;
trimline_bore_length = 2 * ball_r+2;

// Define dimensions of flag line path in terms of the trimline bore and the ball radius
flag_line_width=2*trimline_bore_r;
flag_line_path_radius=ball_r;

// Define dimension of the flag line guide path
a_axis = 2;
b_axis = 4;
major_radius = trimline_bore_r;

// define cross sectional view parameters
cross_section_edge = 100;

// Rotate the kite side down for easier printing
rotate([90,0,0])
    difference() {
        spinner_ball_without_flag_line_path();
        flag_line_path(width=flag_line_width,path_r=flag_line_path_radius);
        //cross_section(cross_section_edge);
    }

module spinner_ball_without_flag_line_path() {
   difference() {
        union() {
            half_squashed_sphere(ball_r, 0.75);
            flag_line_guide(a_axis, b_axis, major_radius);
        }
        cleat_end();
        trimline_bore(trimline_bore_length, trimline_bore_r);
    }
}

module cross_section(cross_section_edge) {
    translate([-cross_section_edge/2,-cross_section_edge/2,0]) cube(cross_section_edge);
}

module flag_line_path(width,path_r) {
    rotate([-90,0,90])
        translate([0.3*width,0,-0.1*width]){  // these offsets were determined through trial and error to resemble successful hand-carved pieces
            union() { // make a shicane from three 1/4 tori
                rotate(a=[90,90,0]) quarter_torus(width, path_r);
                rotate([-90,0,0]) translate([0, -2*path_r, 0]) partial_torus(width, path_r);
            }
        }
}

module trimline_bore(trimline_bore_length, trimline_bore_r) {
    rotate([90,0,0])
        cylinder(h=trimline_bore_length,r=trimline_bore_r,center=true);
}

module flag_line_guide(a_axis, b_axis, major_radius) {
translate([-1 * ball_r,-0.3*b_axis,0])
    rotate([90,0,0])
        elliptical_torus(a_axis, b_axis, major_radius);
}

module cleat_end() {
  // Align the cleat with the x, y, and z axes
  translate([4,34.3,-1])
    rotate([-1,-22,-2])
      import( "/Users/pbchase/git/github/kite_bar_parts/CL826-11AN_20190212_truncated_and_hulled.stl"); 
}

module cleat() {
  // Align the cleat with the x, y, and z axes
  translate([4,34.3,-1])
    rotate([-1,-22,-2])
      import( "/Users/pbchase/git/github/kite_bar_parts/CL826-11AN_20190212_partially_truncated.stl"); 
}

module half_cube_minus_cylinder(r) {
    cube_ratio = 4;
    difference() {
        cube_minus_cylinder(r, cube_ratio);
        translate([0,-1 * cube_ratio *r,0])
            cube(2*cube_ratio*r, center=true);
    }
}

module cube_minus_cylinder(r, cube_ratio) {
    local_cube_ratio = 0.6666667 *cube_ratio;
  difference() {
      cube(2*local_cube_ratio*r, center=true);
      translate([0,0,-r]) {cylinder(h=2*r, r1=r, r2=r);}
  }
}

module half_squashed_sphere(ball_r, squash) {
    union()  {
    squashed_hemisphere(ball_r, squash);
    rotate([0,0,180])
        squashed_hemisphere(ball_r, 1.0);
    }
}


module squashed_hemisphere(radius, squash) {
    // squash will scale in x, leaving z and y unchanged
    scale([1,squash,1])
        hemisphere(radius);
}

module hemisphere(radius) {
    difference() {
        sphere(radius);
        translate([-radius-1,0,-radius-1])
           cube(radius*2+2);
    }
}

// Because my openscad is old I have to extrude 360 degrees of torus before pruning it back.
module quarter_torus(width, path_r) {
    difference() {
        rotate_extrude()
        translate([path_r, 0, 0])
        circle(r = width/2, $fn = 30);
        union() { // remove 3/4 of the torus
            translate([path_r,path_r,0]) cube(2*path_r,center=true);
            translate([-path_r,-path_r,0]) cube(2*path_r,center=true);
            translate([path_r,-path_r,0]) cube(2*path_r,center=true);
        }
    }
}

module partial_torus(width, path_r) {
    difference() {
        rotate_extrude()
        translate([path_r, 0, 0])
        circle(r = width/2, $fn = 30);
        union() { // remove 3/4 of the torus
            translate([0,0,-1*width]) cylinder(h=width*2, r=path_r-1)
            translate([path_r,path_r,0]) cube(2*path_r,center=true);
            rotate([0,0,-58])
                translate([-path_r,-path_r,0]) cube(2*path_r,center=true);
            translate([-path_r,-path_r,0]) cube(2*path_r,center=true);
            translate([path_r,-path_r,0]) cube(2*path_r,center=true);
        }
    }
}

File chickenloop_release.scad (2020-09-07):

// 3D model for a chickenloop release for a kite-bar control system
// The chickenloop release is the thing you push away to release the kite from your harness.
// Make one per kite bar
// Author: Philip B Chase, <philipbchase@gmail.com>
/* This component functions as the release for the chickenloop and a below-the-bar handle for the kite. It must be comfortable when gripping a timmed-out kite. It must slide freely on a doubled trimline of 4mm Amsteel Blue. The Amsteel passes through the large center bore. A stainless steel pin of about 1/8" diameter, crosses and divides the center bore to provide a retainer for the trimline. In addition to the trimline and the retaining pin, the center bore must be large enough to accommodate a 40mm cotter pin used to retain the free end of the chickenloop. The side bores retain a segment of 1/8" bungie that pushes the chickenloop release down onto the cotter pin. These bores must be long enough to allow enough bungie to stretch 40mm so the chickenloop release can easily be pulled off the cotter pin to release it.

    This component should be printed with 100% infill.

*/
/* License: To the extent possible under law, Philip B Chase has waived all copyright and related or neighboring rights to 3D model for a chickenloop release for a kite-bar control system. This work is published from: United States.  See: http://creativecommons.org/publicdomain/zero/1.0/
*/

use <rounded_cylinder.scad>;

$fn=30;

// Body dimensions
overall_width=24;  // x
overall_depth=overall_width;  // y
overall_height=40; // z
// radii of block corners and edges
r_body = 3;

// Dimensions of central bore
// Drill out to 3/16"
central_bore_radius = 0.5 * 25.4 / 2;
central_bore_length = overall_height + 2;

// Dimensions of bungie bore
bungie_bore_radius = 7/64 * 25.4 / 2; 
bungie_bore_length = overall_height + 2;
bungie_bore_x_offset = 8.5;

// Dimensions of retaining pin bore
// See https://www.mcmaster.com/89085K87
pin_bore_radius = 0.102 * 25.4 / 2; 
pin_bore_length = overall_depth + 2;
pin_bore_z_offset = overall_height / 2 - r_body - pin_bore_radius;


difference() {
    cylindrical_body(overall_width, overall_depth, overall_height, r_body);
    central_bore(central_bore_radius, central_bore_length);
    flying_line_bore(bungie_bore_radius, bungie_bore_length, bungie_bore_x_offset);
    flying_line_bore(bungie_bore_radius, bungie_bore_length, -bungie_bore_x_offset);
    pin_bore(pin_bore_radius, pin_bore_length, -pin_bore_z_offset);
}


module central_bore(radius, length) {
    cylinder(h=length, r=radius, center=true);
}

module flying_line_bore(radius, length, x_offset) {
    translate([x_offset,0,0])
        cylinder(h=length, r=radius, center=true);
}

module pin_bore(radius, length, z_offset) {
    translate([0,0,z_offset])
        rotate([90,0,60])
            cylinder(h=length, r=radius, center=true);
}

module cylindrical_body(overall_width, overall_depth, overall_height, radius_of_edges) {
    major_radius = overall_width/2;
    y_scale = overall_depth/overall_width;
    scale([1,y_scale,1]) {
        rounded_cylinder_2(overall_height, major_radius, radius_of_edges);
    }
}

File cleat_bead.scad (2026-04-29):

// 3D model for a cleat bead for a kite-bar control system
// See http://philipbchase.com/
// Make one per kite bar
// Author: Philip B Chase, <philipbchase@gmail.com>
/* This design is meant to mate on to the pilot-end of Clamcleat® CL826-11. It fits tightly onto the end with a positive rotational lock. The spherical shape conforms to the circular hole in the kite-side of the bar and allows for easy bar spinning.  The rotational lock allows for a flag-line guide path to be routed away from the jaws of the cleat to reduce the risk of cleating the flag line.
*/
// Version: 1.1.0
// File: cleat_bead.scad
/* License: To the extent possible under law, Philip B Chase has waived all copyright and related or neighboring rights to 3D model for a cleat bead for a kite-bar control system. This work is published from: United States.  See: http://creativecommons.org/publicdomain/zero/1.0/

    Scans of the Clamcleat CL826-11AN are copyright Clamcleats Limited, UK
*/

use <elliptical_torus.scad>;
use <fillet_around_cylinder_base.scad>;
use <rounded_cylinder.scad>;
$fn=40;

// Define major dimension of ball
ball_r = 27/2;
hemisphere_squash_ratio = 0.75;
bead_center_to_back_face = -14;
edge_radius = 1;

// Define dimension of large center bore for the pair of trim lines
// The line diameters here have all been tested using a wrap of insignia cloth
// around the line end to provide a threading end. This slightly increases the
// line diameter, but is very helpful for routing the line through the
// stopper and ball. In each case, the width of the cloth wrapped around the
// line as 4 times the nominal line diameter. Aka, slightly more than Pi and
// slightly more than one wrap.
bore_diameter_for_4mm_amsteel = 1/4 * 25.4;
bore_diameter_for_old_5mm_amsteel = 5/16 * 25.4;
bore_diameter_for_modern_5mm_amsteel = 3/8 * 25.4;
bore_diameter_for_5mm_ultrex = 3/8 * 25.4;
trim_line_diameter=bore_diameter_for_old_5mm_amsteel;

trimline_bore_r=trim_line_diameter/2;
trimline_bore_length = 2 * ball_r+2;
bore_campher_radius = 4.0;
bore_campher_height = 3;

// Define dimensions of flag line path in terms of the trimline bore and the ball radius
flag_line_width=bore_diameter_for_modern_5mm_amsteel;
flag_line_path_radius=ball_r;
flag_line_guide_radius=flag_line_width/2 + 2;

// Define dimension of the flag line guide path
flag_line_path_straight_segment_length = -bead_center_to_back_face;

// Define Set screw dimensions
set_screw_radius = 2;
set_screw_length = 12;
set_screw_height_above_base = 7;

// define cross sectional view parameters
cross_section_edge = 100;

module set_screw_plateau(plateau_radius, set_screw_length) {
    translate([0, set_screw_height_above_base - ball_r, 10])
        rounded_cylinder_2(set_screw_length, plateau_radius, plateau_radius/3);
}


// Rotate the kite side down for easier printing
    rotate([90,0,145])
    difference() {
        cleat_bead_without_flag_line_path();
        flag_line_path(flag_line_width, flag_line_path_radius,flag_line_path_straight_segment_length);
        campher_trimline_bore(ball_r, trimline_bore_r, bore_campher_radius, bore_campher_height);
        //cross_section(cross_section_edge);
        //#cleat();
    }

module cleat_bead_without_flag_line_path() {
   difference() {
        hull() {
            sphere(r=ball_r);
            flag_line_guide(flag_line_guide_radius, 
                flag_line_path_radius, 
                ball_r, 
                bead_center_to_back_face);
            cleat_end_slice(bead_center_to_back_face);
            expand_back_face(edge_radius, bead_center_to_back_face);
            set_screw_plateau(set_screw_radius*3 , 8);
       }
       cleat_end();
       trimline_bore(trimline_bore_length, trimline_bore_r);
       set_screw(set_screw_radius, set_screw_length);
    }
}

module rope_volume_on_right_side_of_cleat() {
    translate([-3,-21,6.5])
        rotate([1,-5,-17])
            scale([6.5,16,5])
                sphere(r=1);
}

module campher_trimline_bore(ball_r, trimline_bore_r, bore_campher_radius, bore_campher_height) {
    translate([0,ball_r-bore_campher_radius + 4.6,0])
        rotate([90,0,0])
            union() {
                fillet_around_cylinder_base(trimline_bore_r, bore_campher_radius, true);
                translate([0,0,-1.5])
                    cylinder(h=bore_campher_height, r=trimline_bore_r+bore_campher_radius, center=true);
            }
}

module cross_section(cross_section_edge) {
    rotate([0,-45,0])
        translate([-cross_section_edge/2,-cross_section_edge/2,0])
            cube(cross_section_edge);
}

module expand_back_face(edge_radius, bead_center_to_back_face) {
    y_disp = bead_center_to_back_face + edge_radius;
    translate([-6.6,y_disp,1.6]) rotate([90,0,0]) elliptical_torus(edge_radius, edge_radius, 5.2);
    translate([-2.0,y_disp,3.5]) rotate([90,0,0]) elliptical_torus(edge_radius, edge_radius, 7.4);
}

module flag_line_path(width,path_r,flag_line_path_straight_segment_length) {
    translate([0,0,0])
    rotate([-90,135,0])
        union() { // make a cylinder with a 1/4 torus end
                rotate(a=[90,90,0]) quarter_torus(width, path_r);
                translate([path_r, 0, -0.5*flag_line_path_straight_segment_length])
                    union() {
                        cylinder(h=1.0004 * flag_line_path_straight_segment_length, r=width/2, center=true);
                        translate([0,0,-0.5002*flag_line_path_straight_segment_length])
                            fillet_around_cylinder_base(width/2, 1, true);
                    }
        }
}

module flag_line_guide(radius, flag_line_path_radius, ball_r, bead_center_to_back_face) {
    torus_minor_r=1;
    rotate([0,45,0]) {
        // shape the front with a half-sphere
        translate([0,bead_center_to_back_face + radius,-flag_line_path_radius])
            difference() {
                sphere(radius);
                rotate([90,0,0])
                    cylinder(h=radius, r=radius);
            }
        // Place a torus at the back face.
        translate([0, bead_center_to_back_face + torus_minor_r,-flag_line_path_radius])
            rotate([90,0,0])
                elliptical_torus(torus_minor_r, torus_minor_r, radius - 2*torus_minor_r);
    }
}

module trimline_bore(trimline_bore_length, trimline_bore_r) {
    rotate([90,0,0])
        cylinder(h=trimline_bore_length,r=trimline_bore_r,center=true);
}

module set_screw(set_screw_radius, set_screw_length) {
    translate([0, set_screw_height_above_base - ball_r, 10])
            cylinder(h=set_screw_length,r=set_screw_radius,center=true);
}

module cleat_end_slice(bead_center_to_back_face) {
    slice_thickness = 1;
    slice_edge_radius = 1;
    minkowski() {
        intersection() {
            cleat_end();
            translate([0,bead_center_to_back_face + slice_edge_radius + slice_thickness/2,0]) cube([20,slice_thickness,20], center=true);
        }
        sphere(r=slice_edge_radius);
    }
}

module cleat_end() {
  // Align the cleat with the x, y, and z axes
  translate([0,4,0])
  union() {
      translate([4,34.3,-1])
        rotate([-1,-22,-2])
          import( "CL826-11AN_20190212_truncated_and_hulled.stl");
      rope_volume_on_right_side_of_cleat();
  }
}

module cleat() {
  // Align the cleat with the x, y, and z axes
  translate([0,4,0])
  translate([4,34.3,-1])
    rotate([-1,-22,-2])
      import( "CL826-11AN_20190212_partially_truncated.stl");
}

// Because my openscad is old I have to extrude 360 degrees of torus before pruning it back.
module quarter_torus(width, path_r) {
    difference() {
        rotate_extrude()
        translate([path_r, 0, 0])
        circle(r = width/2, $fn = 15);
        union() { // remove 3/4 of the torus
            translate([path_r,path_r,0]) cube(2*path_r,center=true);
            translate([-path_r,-path_r,0]) cube(2*path_r,center=true);
            translate([path_r,-path_r,0]) cube(2*path_r,center=true);
        }
    }
}

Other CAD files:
printable/cleat_bead_cb0d3b8.stl
printable/separation_block_v1_9a972b6.stl
elliptical_cone.scad
elliptical_torus.scad
fillet_around_cylinder_base.scad
rounded_cylinder.scad
separation_block_v1.scad
separation_block_v2.scad
separation_block_v3.scad
stopper_ball.scad
stopper_block.scad
stopper_block_v3.scad
stopper_block_v4.scad
trapezoided_cube.scad
wichard_snaphook_cone_fid.scad
wichard_snaphook_handle.scad
wichard_snaphook_handle_concave_link.scad
wichard_snaphook_handle_for_cone_fid.scad
wichard_snaphook_handle_golf_tee_style.scad
wichard_snaphook_release_cone.scad
wichard_snaphook_release_cone_and_handle.scad

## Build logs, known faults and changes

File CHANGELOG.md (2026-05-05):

# kite_bar_parts 1.7.1 (released 2026-05-05)
- Remove text from the separation_block (@pbchase)

# kite_bar_parts 1.7.0 (released 2026-04-28)
- Update cleat_bead.scad (@pbchase)
    - Increase set screw plateau radius to set_screw_radius*3.
    - Update STL to the new model.
    - Update README.md

# kite_bar_parts 1.6.0 (released 2025-09-27)
- Document latest cleat bead (@pbchase)
Use two images of the cleat bead.
Describe the addition and installation of the set screw.
Update the STL.

- Update cleat_bead.scad (@pbchase)
Add set_screw_plateau().
Add a bore hole for the set screw.

- Update README.md (@pbchase)
Replace separation_block_v2 with separation_block_v3
Move multiple old models to v3

- Add separation_block_v3 (@pbchase)
Provides an 8mm trimline bore for a brummel-spliced 4mm Amsteel Blue line.
Adds label text.

## [1.5.0] - 2020-09-07
### Added
- Add chickenloop_release.scad and rounded_cylinder_2 (Philip Chase)
- Add first version of cleat jacket template (Philip Chase)

### Changed
- Promote separation_block_v2 to a tested model (Philip Chase)
- Move models in phase out into 'Older models' section  (Philip Chase)
- Update separation_block_v2 STL and README reference (Philip Chase)
- Resize body and trimline bore of separation_block_v2 (Philip Chase

## [1.4.2] - 2019-05-05
### Changed
- Promote the cleat bead to a tested model (Philip Chase)
- Update cleat_bead and separation_block_v1 STLs to 80 facets (Philip Chase)

## [1.4.1] - 2019-02-19
### Changed
- Realign the flag line path with the sphere surface and campher the trimline_bore in cleat_bead (Philip Chase)
- Expand back face of cleat bead to have 1mm thick, radiused edges (Philip Chase)
- Make the cleat_bead taller, add a radius to the base, widen flag_line_path, use true sphere for bead body (Philip Chase)

## [1.4.0] - 2019-02-16
### Added
- Add cleat_bead, an interface between the cleat, bar and flag line to substitute for a moveable stopper [Philip Chase]

## [1.3.0] - 2018-09-25
### Added
 - Add three-part, segmented wichard snaphook - Philip Chase

### Changed
 - Narrow the width of the flange to match the height in stopper_block_v4 so as to diminish interference when cleating the trimline - Philip Chase
 - Form the stopper block flange with a hulled, squashed torus - Philip Chase
 - Rotate the cross bores in the stopper ball to eliminate the twisting of the bungie inside the block's bungie path - Philip Chase
 - Use a broad flat base on the stopper ball to reduce separation from the raft during printing - Philip Chase
 - Add trimline bore diameter for multiple lines sizes to stopper ball and stopper_block_v4 standardizing on modern 5mm amsteel - Philip Chase
 - Parameterize and adjust magnet, bungie path, and block depth of stopper_block_v4 - Philip Chase

## [1.2.0] - 2018-08-12
### Added
 - Add separation_block_v2 - Philip Chase
 - Add separation_block - Philip Chase
 - Add STL files for all fiels that did not have them

### Changed
 - Move the documentation for older designs and primitives to their own files - Philip Chase
 - Extend flange of stopper_block_v4 laterally to make it more comfortable to push - Philip Chase

## [1.1.0] - 2018-06-24
### Added
 - Add stopper_block_v4 a narrow, rounded block with a wide pushable flange on the backside - Philip Chase
 - Add elliptical_sphere to elliptical_torus.scad - Philip Chase
 - Add trapezoided_cube.scad - Philip Chase

### Changed
 - Fatten the contact surface at the base of the cone at the bottom of the stopper_ball - Philip Chase

## [1.0.0] - 2018-06-10
### Added
- First release provides these designs:
-   stopper_ball
-   stopper_block
-   stopper_block_v2
-   stopper_block_v3
-   wichard_snaphook_handle
-   wichard_snaphook_handle_golf_tee_style
-   wichard_snaphook_release_cone

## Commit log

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2016-04-13 Parameterize the initial cube and the hull of the stopper block
    [stopper_block.scad]
2016-04-13 Parameterize the diameter, dimensions and gross position of the safety line hole
    [stopper_block.scad]
2016-04-14 Parameterize bungie cross bore and add new parameter thickness_of_main_body in place of 1/2 overall_height
    [stopper_block.scad]
2016-04-14 Parameterize trimline holes and remove camphers on their ends
    [stopper_block.scad]
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2016-10-22 Add model of a cone for releasing a Wichard quick release snap shackle
    [wichard_snaphook_release_cone.scad]
2016-10-22 Add a 3D model for a handle with cone to release a Wichard quick release snap shackle
    [wichard_snaphook_release_cone_and_handle.scad]
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2016-10-22 Replace straight cone with elliptical cone and change radii to actual radii in wichard_snaphook_release_cone_and_handle.scad
    [wichard_snaphook_release_cone_and_handle.scad]
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2016-11-09 On wichard_snaphook_release_cone_and_handle, reduce center bore to accommodate a folded 300# spectra line and increase the cone tip diameter to 4.5 mm.
    [wichard_snaphook_release_cone_and_handle.scad, wichard_snaphook_release_cone_and_handle.stl]
2016-11-22 Use true cone cone in snaphook trigger to get more reliable release
    * Set the cone slope according to testing on the snap shackles.
    * Set tip diameter to 4.5 mm.
    * Increase bore diameter from ~1.9 - 2.5mm
    [wichard_snaphook_release_cone_and_handle.scad]
2016-11-24 Improve comments in snaphook handle design
    Create separate sections for assembly and use.
    Fix typos.
    [wichard_snaphook_release_cone_and_handle.scad]
2016-11-24 Remove more material inside snaphook handle
    Increase the radius and height of the cutout sphere inside snaphook handle.
    [wichard_snaphook_release_cone_and_handle.scad]
2016-11-24 Add the means to make a cross-section of the snaphook handle
    Add a temporary layer that can be used to make a cross-section of the
    snaphook handle on the vertical axis of symmetry during design work.
    [wichard_snaphook_release_cone_and_handle.scad]
2016-11-24 Remove STL file of snaphook handle because it is out of date
    [wichard_snaphook_release_cone_and_handle.stl]
2016-11-24 Rename wichard snaphook handle
    [wichard_snaphook_handle.scad]
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2018-04-22 wichard_snaphook_handle bore radius to 1mm, tip od to 4mm
    [wichard_snaphook_handle.scad]
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2018-05-20 Add 'golf tee' style snaphook handle
    [wichard_snaphook_handle_golf_tee_style.scad]
2018-05-20 Add a module to generate an elliptical torus
    [elliptical_torus.scad]
2018-05-20 Add a 22 degree beveled cap to the hollow of the golf tee
    [wichard_snaphook_handle_golf_tee_style.scad]
2018-05-20 Expand and reformat the comments for the golf tee
    [wichard_snaphook_handle_golf_tee_style.scad]
2018-05-20 Reduce the bore to 3/32" and round the cone height on the golf tee
    [wichard_snaphook_handle_golf_tee_style.scad]
2018-05-30 Reference correct function name in fillet_around_cylinder_base.scad
    [fillet_around_cylinder_base.scad]
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2018-06-09 Use reduced facet count on the base to correct overhangs at the base in stopper_block_v2
    [stopper_block_v2.scad]
2018-06-09 Replace stopper_block_v2 image with the current model
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2018-06-09 Narrow stopper_block_v3 and make horizontal bores octagonal to address overhang issues
    [stopper_block_v3.scad]
2018-06-09 Use a cone-shaped bottom in the magnet hole to reduce the risk of print overhang issues in stopper_block_v3
    [stopper_block_v3.scad]
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2018-06-10 Revise flag line path to provide rounded edges and replace special vars with regular vars in stopper_block_v3.scad
    [stopper_block_v3.scad]
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2018-06-10 Add another golden mean in Prism for Upper section of stopper_block_v3.scad
    [stopper_block_v3.scad]
2018-06-10 Enlarge stopper_ball and fix overhung printing issues
    [stopper_ball.scad]
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2018-06-12 Widen bungie cross bore and move magnet hole down
    [stopper_block_v3.scad]
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2018-06-16 Add stopper_block_v4 a narrow, rounded block with a wide pushable flange on the backside
    [stopper_block_v4.scad]
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2018-06-24 Revert "Remove conical end of stopper_ball"
    This reverts commit 083d8ed64f39965e3b93a3d2e227fc7fb1632735.
    [stopper_ball.scad]
2018-06-24 Fatten the contact surface at the base of the cone at the bottom of the stopper_ball
    [stopper_ball.scad]
2018-06-24 Fix typos in comments in stopper_ball
    [stopper_ball.scad]
2018-07-08 Extend flange of stopper_block_v4 laterally to make it more comfortable to push
    [stopper_block_v4.scad]
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2018-08-08 Change separation block to 22mm width and 6.5 mainline offset
    [separation_block_v1.scad]
2018-08-09 Replace elliptical ends of separation_block with flat ends
    [rounded_cylinder.scad, separation_block_v1.scad]
2018-08-11 Expand separation_block to get clearance between main lines and central bore
    [separation_block_v1.scad]
2018-08-12 Add basic separation_block_v2 with a U-shaped trimline bore
    [separation_block_v2.scad]
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2018-08-13 Add trim line bore toroids to clean up hole edges and increase overall_width in separation_block_v2
    [separation_block_v2.scad]
2018-08-13 Add separation_block_v2 to README and fix comments for same
    [separation_block_v2.scad]
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2018-09-03 Add trimline bore diameter for multiple lines standardizing on modern 5mm amsteel
    [stopper_block_v4.scad]
2018-09-03 Refactor magnet and bungie path to parameterize and reposition each and resize bungie path
    [stopper_block_v4.scad]
2018-09-03 Refactor and reshape the cut away that reveals interior clearances
    [stopper_block_v4.scad]
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2018-09-03 Add trimline bore diameter for multiple lines to stopper ball standardizing on modern 5mm amsteel
    [stopper_ball.scad]
2018-09-03 Add new STLs for stopper_ball, stopper block and snaphook handles
    [stopper_ball_4mm_amsteel_30c9f20.stl, stopper_ball_modern_5mm_amsteel_30c9f20.stl, stopper_block_v4_4mm_amsteel_30c9f20.stl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]
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2018-09-07 Use a broad flat base on the stopper ball to reduce separation from the raft during printing
    [stopper_ball.scad]
2018-09-07 Rotate the cross bores in the stopper ball to eliminate the twisting of the bungie inside the block's bungie path
    [stopper_ball.scad]
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2018-09-11 Squashed sphere used to form the stopper block flange with a hulled, squashed torus
    [elliptical_torus.scad, stopper_block_v4.scad]
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2018-09-26 Narrow the width of the flange to match the height so as to diminish interfere when cleating the trimline
    [stopper_block_v4.scad, stopper_block_v4_4mm_amsteel.stl, stopper_block_v4_modern_5mm_amsteel.stl]
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2019-02-14 Rotate the kite side of the spinner ball down for easier printing and reduce the facet count
    [spinner_ball.scad]
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2019-02-16 Change flag line guide into a sphere hulled to the ball, rotate to the left side of the ball, clean out the cruft
    [cleat_bead.scad]
2019-02-16 Extend the flag line guide toward the kite and add a chamfer at its entrance on the cleat bead
    [cleat_bead.scad]
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2019-02-16 Extend body of bead toward kite to form a uniform plane using cleat_end_slice
    [cleat_bead.scad]
2019-02-16 Move the sphere of the flag_line_guide towards the back of the cleat_bead
    [cleat_bead.scad]
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2019-02-16 Push cleat end deeper into cleat bead and thicken base of bead
    [cleat_bead.scad]
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2019-02-19 Make the cleat_bead taller, add a radius to the base, widen flag_line_path, use true sphere for bead body, and remove dead code
    [cleat_bead.scad]
2019-02-19 Expand back face of cleat bead to have 1mm thick, radiused edges
    [cleat_bead.scad]
2019-02-19 Realign the flag line path with the sphere surface and campher the trimline_bore in cleat_bead
    [cleat_bead.scad]
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2019-05-22 Resize body and trimline bore of separation_block_v2
    Reduce height.
    Narrow body width.
    Match major radius of trimline bore to body width.
    Raise trimline bore.
    [separation_block_v2.scad]
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2025-09-26 Add separation_block_v3
    Provides an 8mm trimline bore for a brummel-spliced 4mm Amsteel Blue line.
    Adds label text.
    [separation_block_v3.scad]
2025-09-26 Update README.md
    Replace separation_block_v2 with separation_block_v3
    Add png and stl of separation_block_v3
    Move multiple old models to v3
    [separation_block_v3_8mm_trimline_bore_e90f9fc.stl]
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2025-09-28 Document latest cleat bead
    Use two images of the cleat bead.
    Describe the addition and installation of the set screw.
    Update the STL.
    [cleat_bead_cb0d3b8.stl]
2026-04-29 Update cleat_bead.scad
    Increase set screw plateau radius to set_screw_radius*3.
    Update STL to the new model.
    [cleat_bead.scad, cleat_bead_2026-04-28.stl, cleat_bead_ff7e41a.stl]
2026-04-29 Update cleat_bead.scad
    Update README.md
    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
    [cleat_bead.scad, cleat_bead_2026-04-28.stl, cleat_bead_ff7e41a.stl]
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
